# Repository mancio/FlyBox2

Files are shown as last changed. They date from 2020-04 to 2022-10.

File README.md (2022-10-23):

# FlyBox2

<p align="center">
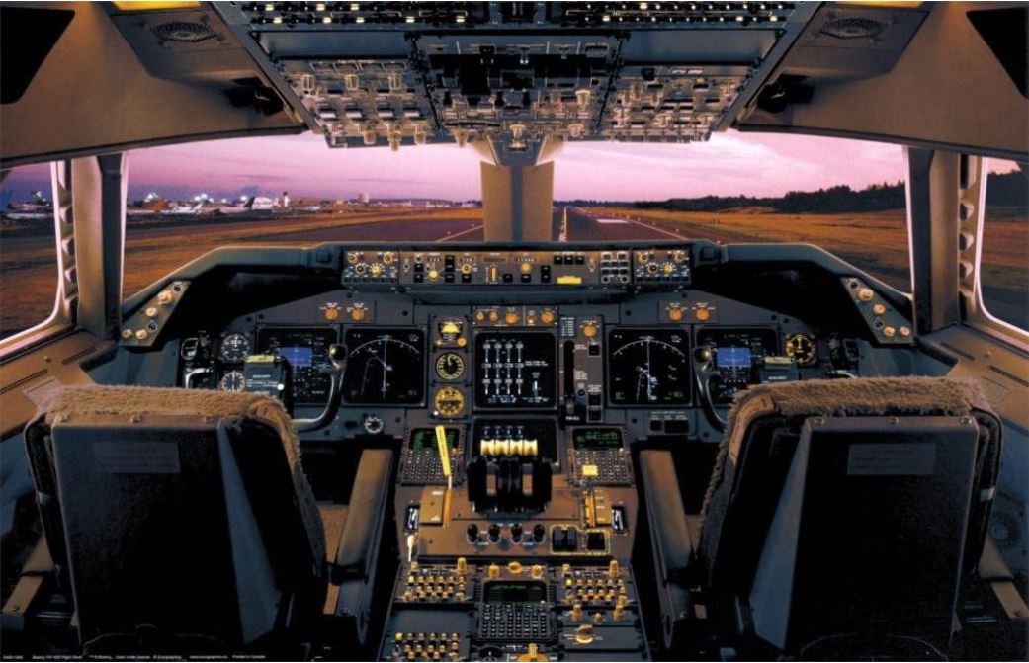
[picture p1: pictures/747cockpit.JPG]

</p>

An advanced flight control pad made with an atmega32u4 pro micro (leonardo architecture)

This idea is the evolution of the first [FlyBox](https://github.com/mancio/FlyBox) a pad to be used with a joystick to control all the operation with the hand free from the axis flight controls. FlyBox2 bring the basic idea to a new level.
To keep low prices is possible to use two Arduino and a multiplexer to have multiple interrupt pins for encoders and many push button.
The main Arduino will collect signal from the other and will send to the PC using the HID driver. 

## The Arduino Pro Micro
[Full Pinout](https://cdn.sparkfun.com/datasheets/Dev/Arduino/Boards/ProMicro16MHzv1.pdf)

For better performance remember to use interrupt pins for encoder. 

Interrupt pins are 0,1,2,3,7.

## IDE
VS Studio Visual Studio Code 

## Schematics

<p align="center">
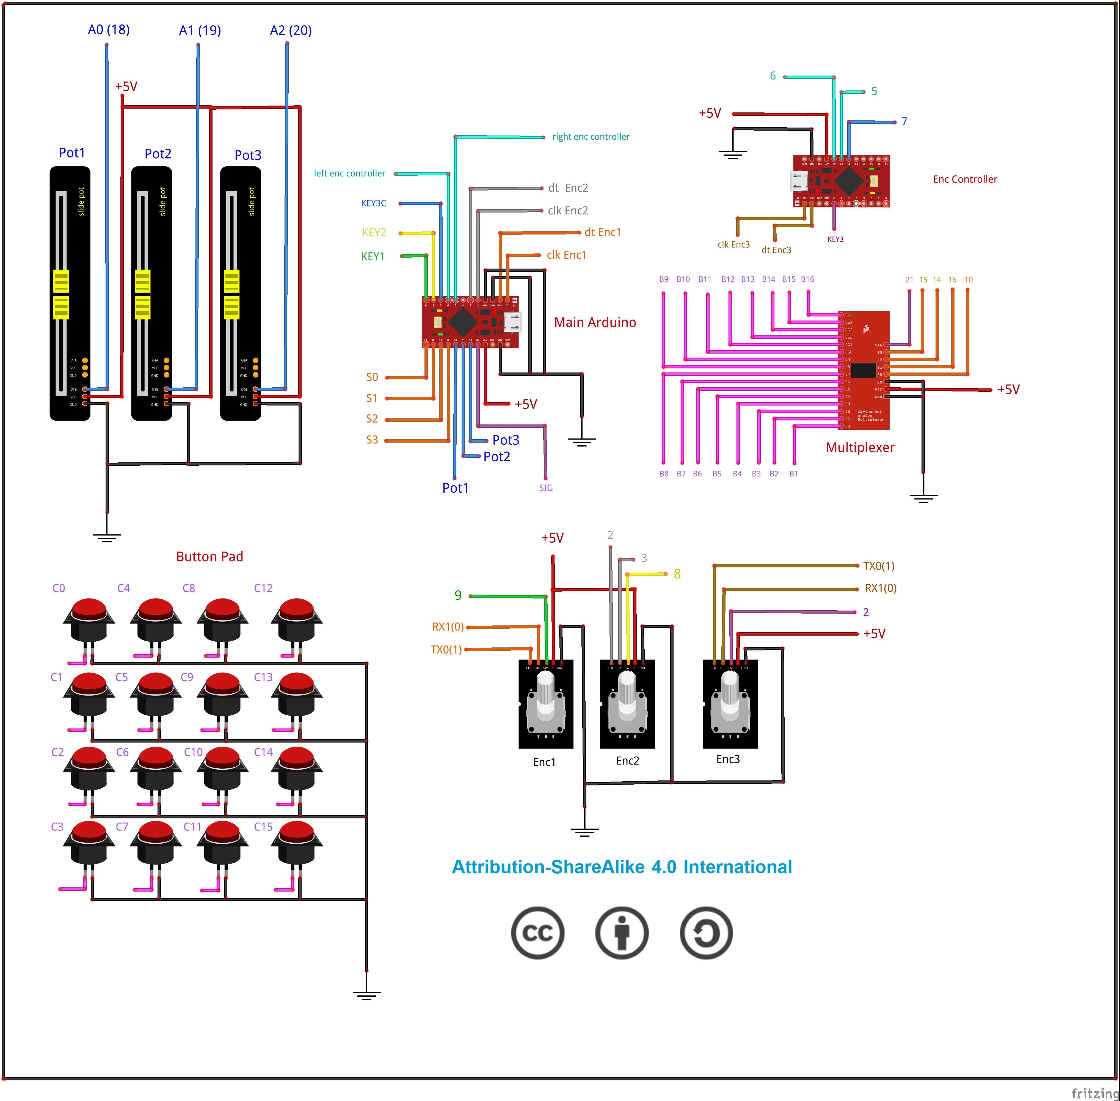
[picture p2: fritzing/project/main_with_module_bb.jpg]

</p>

## MC14490P Signal Debounce Module

I build a small module to fit the [MC14490P](https://www.onsemi.com/pub/Collateral/MC14490-D.PDF) a debouncer signal chip. The delay can be changed by changing the cap impedance. Bigger value = bigger delay.
The hardware approach help the software debounce, anyway is just an optional.

You can find the board ready to print on [OSHPark](https://oshpark.com/shared_projects/8fIAeRlI)

## The encoder tragedy 

Unfortunately the Pro Micro has only 5 interrupt (pins: 0,1,2,3,7). If we wire the encoder output pins to not-external interrupt pins of Arduino, the encoder will become very imprecise showing movement in the both directions during one side turn of the knob.
This happen because classic pins can be read every loop, instead an external interrupt is catch immediately, so we can say like is "over the loop".
Every encoder need 2 interrupts so we do not have enough pins available for 3 or more knobs.

To solve this issue I decide to build an additional module to attach to this board: [The FlyBox2_encoder_module](https://github.com/mancio/FlyBox2_encoder_module)

## The CD74HC4067 Multiplexer

The multiplexer give the possibility, as the name say, to have many output from few inputs. This can be done by using a
reading input pin and a function that connect all the multiplexed pin to this input one by one. The switch is done by using a [truth table](https://www.instructables.com/id/Tutorial-74HC4067-16-Channel-Analog-Multiplexer-De/).

One easier solution should be using a button matrix having less pins but in this case I cannot press multiple button at the same 
time.

## Component list

* 1x Arduino pro micro atmega32u4 (native USB port not like Arduino nano)
* 3x 10k slide potentiometers
* 3x rotary encoders 
* 1x CD74HC4067 16-Channel Analog Digital Multiplexers
* 1x MC14490P hardware debouncer
* 1x 10nf capacitor(change capacitor change delay)
* 16X push buttons

## Documentation

[Here](http://mancioboxblog.altervista.org/flybox2Doc/files.html) you can find the documentations written in Doxygen 

## Installation

* upload the code of Flybox2 to the main arduino
* unplug the usb from this arduino and plug to the second one
* upload the code of the [Flybox2_encoder_module](https://github.com/mancio/FlyBox2_encoder_module) to the second arduino
* unplug usb and plug again to the first one to play

NOTE: DO NOT PLUG TWO USB AT THE SAME TIME. 5V+ AND GND ARE IN COMMON ON BOTH ARDUINO
ALTHOUGH NOTHING BAD SHOULD HAPPEN IS NOT RECOMMENDED TO HAVE TWO POWER SOURCES.

## Clion UPDATE

For people who like Intellj CLion IDE

* install PlatformIO plug in
* search ``Cmake`` in ``Settings`` and click ``+`` button to add ``Debug``, ``leonardo`` and ``Default``
* install python3
* autogenerate ``CmakeList.txt`` if not present
* add PlatformIO configuration on the top dropdown list (build/play section)
* remove build execution from the configuration list of this new configuration
* play the configuration with leonardo selected ``PlatformIO Upload|leonardo``

some links:
* [tutorial](https://docs.platformio.org/en/latest/integration/ide/clion.html)
* [python trick](https://community.platformio.org/t/could-not-find-the-package-with-requirements-for-your-system-windows-amd64/18416)

## Sliding potentiometer UPDATE

Some sim like DCS are more sensible to potentiometer flickering. As you may notice classic hobbyist use 
pot slide and not, due to their cheap building are not keeping constant resistance in some position.
You will see the throttle of your plane vibrate and changing speed.
This problem can be solved by adding a capacitor (same concept as button debouncing) or via software.
Speaking about the software way, I found a [solution online](https://www.norwegiancreations.com/2015/10/tutorial-potentiometers-with-arduino-and-filtering/) that
involve a moving average algorithm. Even though look like very professional, I thought something much 
more simple. my code has a

* pot map function (from Arduino library)
* joystick function top set the axis scale (from Joystick.h)

With the first I can map the slider following the arduino library suggestions and with the second I can choose
how many axis positions the joystick can take (read by the operating system).
If I map a bigger range of int numbers in one smaller I will have multiple numbers in input assigned to the same
number in output. This magically will remove the vibration!.... so much math saved :)

## Altium Design

In Altium design folder you can find the design for
* [FlyBox2 Main Board](https://github.com/mancio/FlyBox2/tree/master/AltiumProject/Flybox2_main_board)
* [16 Push Button Pad](https://github.com/mancio/FlyBox2/tree/master/AltiumProject/ButtonPad)
* [Breakout module for encoders](https://github.com/mancio/FlyBox2/tree/master/AltiumProject/Encoder_Breakout_Module)
* [Breakout module for potentiometer](https://github.com/mancio/FlyBox2/tree/master/AltiumProject/Potentiometer_breakout_module)
* [Debounce signal module](https://github.com/mancio/FlyBox2/tree/master/AltiumProject/MC14490P_module)

Gerbers file are generated by .OutJob file. This file need to be configured in different why depending by the
format accepted by the printer service.
Altium using the job file is able to generate the gerber file in the specified folder. You need just to zip the output in a single file and upload it on your favorite printing web site service.

I tried
* [OSH Park](https://oshpark.com/)
* [Aisler](https://aisler.net/)
* [JLCPCB](https://jlcpcb.com/)

OSH Park unfortunately seem to be the most problematic accepting files. Is possible you need to customize the .zip file.
The others are fine.

Always write directly to the customer service to check if the design is fine before ordering. Every service interpret gerber
files in different ways.

## Box Design

I tried to design the box using cardboard and unfortunately the result wasn't so good. 
I made the template using Adobe Illustrator because is able to manage svg files. [Here](https://github.com/mancio/FlyBox2/tree/master/artdesign) you can find the project.

Looking for a better solution, I made a box using Fusion 360 [here](https://github.com/mancio/FlyBox2/tree/master/artdesign/fusion360). 

Now is the time for printing and if you live in Poland you can look at [this site](https://send3d.eu/). I still have to try them but price are amazing!

## TODO

* video on youtube (to show how much I'm cool 😎)

## What next?

* improve encoder functionality (when it turn fast is recognize as single click)
* refurbish the design using a Teensy (it has multiple interrupt pins and bigger frequency)
* try using a fpga board (push buttons operation and encoding can be hardwired to save CPU)

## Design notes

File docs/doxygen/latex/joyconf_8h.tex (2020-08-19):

\hypertarget{joyconf_8h}{}\doxysection{C\+:/\+Users/mancio/\+Documents/\+V\+S\+Code/\+Fly\+Box2/include/joyconf.h File Reference}
\label{joyconf_8h}\index{C:/Users/mancio/Documents/VSCode/FlyBox2/include/joyconf.h@{C:/Users/mancio/Documents/VSCode/FlyBox2/include/joyconf.h}}
\doxysubsection*{Macros}
\begin{DoxyCompactItemize}
\item 
\#define \mbox{\hyperlink{joyconf_8h_af62b1614b9bf8609ff4f99706498dade}{N\+O\+\_\+\+R\+EV}}~true
\item 
\#define \mbox{\hyperlink{joyconf_8h_a33a42d6bfefe54ae2384f5c28dd87340}{R\+EV}}~false
\end{DoxyCompactItemize}
\doxysubsection*{Functions}
\begin{DoxyCompactItemize}
\item 
void \mbox{\hyperlink{joyconf_8h_afab08082007163b964f41ba8334b865a}{set\+Test}} (bool testin)
\item 
void \mbox{\hyperlink{joyconf_8h_aba818122d70d2c4ac723a578e75f7a3e}{joy\+\_\+conf}} ()
\item 
int \mbox{\hyperlink{joyconf_8h_af953debc945efa2555f04021970412cc}{debouncer}} (int button)
\item 
void \mbox{\hyperlink{joyconf_8h_a8cb8e263f5b6ea299e26646c0c08ce44}{btset}} (int pin, int button)
\item 
long \mbox{\hyperlink{joyconf_8h_a49cc520c407e8c57083155e620ed15d6}{mapper}} (long m, bool rev)
\item 
long \mbox{\hyperlink{joyconf_8h_aca616a67e14e1af19f4c36eedb9ae19d}{setX}} (int pin, bool rev)
\item 
long \mbox{\hyperlink{joyconf_8h_a68d0ce74156f4fb9ca09c7e738bcbf5b}{setY}} (int pin, bool rev)
\item 
long \mbox{\hyperlink{joyconf_8h_a4251eb0b20a921657f56758a51659964}{setZ}} (int pin, bool rev)
\item 
void \mbox{\hyperlink{joyconf_8h_ae830efa40aedd3af609d7ff5d406a782}{bt\+Array\+Filler}} ()
\item 
void \mbox{\hyperlink{joyconf_8h_a7fd8c17ec4e20e74986b3c51041f4026}{mux\+Looper}} ()
\item 
void \mbox{\hyperlink{joyconf_8h_a2b3557d5e92d039ce5744f99efe4efa2}{set\+Encoders\+\_\+dir}} ()
\end{DoxyCompactItemize}

\doxysubsection{Macro Definition Documentation}
\mbox{\Hypertarget{joyconf_8h_af62b1614b9bf8609ff4f99706498dade}\label{joyconf_8h_af62b1614b9bf8609ff4f99706498dade}} 
\index{joyconf.h@{joyconf.h}!NO\_REV@{NO\_REV}}
\index{NO\_REV@{NO\_REV}!joyconf.h@{joyconf.h}}
\doxysubsubsection{\texorpdfstring{NO\_REV}{NO\_REV}}
{\footnotesize\ttfamily \#define N\+O\+\_\+\+R\+EV~true}

Definition at line 26 of file joyconf.\+h.

\mbox{\Hypertarget{joyconf_8h_a33a42d6bfefe54ae2384f5c28dd87340}\label{joyconf_8h_a33a42d6bfefe54ae2384f5c28dd87340}} 
\index{joyconf.h@{joyconf.h}!REV@{REV}}
\index{REV@{REV}!joyconf.h@{joyconf.h}}
\doxysubsubsection{\texorpdfstring{REV}{REV}}
{\footnotesize\ttfamily \#define R\+EV~false}

Definition at line 27 of file joyconf.\+h.

\doxysubsection{Function Documentation}
\mbox{\Hypertarget{joyconf_8h_ae830efa40aedd3af609d7ff5d406a782}\label{joyconf_8h_ae830efa40aedd3af609d7ff5d406a782}} 
\index{joyconf.h@{joyconf.h}!btArrayFiller@{btArrayFiller}}
\index{btArrayFiller@{btArrayFiller}!joyconf.h@{joyconf.h}}
\doxysubsubsection{\texorpdfstring{btArrayFiller()}{btArrayFiller()}}
{\footnotesize\ttfamily void bt\+Array\+Filler (\begin{DoxyParamCaption}{ }\end{DoxyParamCaption})}

build an array of buttons in normal order from 1 to 16 

Definition at line 217 of file joyconf.\+cpp.

\mbox{\Hypertarget{joyconf_8h_a8cb8e263f5b6ea299e26646c0c08ce44}\label{joyconf_8h_a8cb8e263f5b6ea299e26646c0c08ce44}} 
\index{joyconf.h@{joyconf.h}!btset@{btset}}
\index{btset@{btset}!joyconf.h@{joyconf.h}}
\doxysubsubsection{\texorpdfstring{btset()}{btset()}}
{\footnotesize\ttfamily void btset (\begin{DoxyParamCaption}\item[{int}]{pin,  }\item[{int}]{button }\end{DoxyParamCaption})}

set joystick button state according to pin input

\begin{DoxyParams}{Parameters}
{\em int} & input pin \\
\hline
{\em int} & button to be modified \\
\hline
\end{DoxyParams}
\mbox{\Hypertarget{joyconf_8h_af953debc945efa2555f04021970412cc}\label{joyconf_8h_af953debc945efa2555f04021970412cc}} 
\index{joyconf.h@{joyconf.h}!debouncer@{debouncer}}
\index{debouncer@{debouncer}!joyconf.h@{joyconf.h}}
\doxysubsubsection{\texorpdfstring{debouncer()}{debouncer()}}
{\footnotesize\ttfamily int debouncer (\begin{DoxyParamCaption}\item[{int}]{button }\end{DoxyParamCaption})}

debounce the click button (used in addiction with hardware debounce)

\begin{DoxyParams}{Parameters}
{\em int} & button to debounce \\
\hline
\end{DoxyParams}
\begin{DoxyReturn}{Returns}
button state debounced 
\end{DoxyReturn}

Definition at line 138 of file joyconf.\+cpp.

\mbox{\Hypertarget{joyconf_8h_aba818122d70d2c4ac723a578e75f7a3e}\label{joyconf_8h_aba818122d70d2c4ac723a578e75f7a3e}} 
\index{joyconf.h@{joyconf.h}!joy\_conf@{joy\_conf}}
\index{joy\_conf@{joy\_conf}!joyconf.h@{joyconf.h}}
\doxysubsubsection{\texorpdfstring{joy\_conf()}{joy\_conf()}}
{\footnotesize\ttfamily void joy\+\_\+conf (\begin{DoxyParamCaption}{ }\end{DoxyParamCaption})}

Initialize joystick library 

Definition at line 122 of file joyconf.\+cpp.

\mbox{\Hypertarget{joyconf_8h_a49cc520c407e8c57083155e620ed15d6}\label{joyconf_8h_a49cc520c407e8c57083155e620ed15d6}} 
\index{joyconf.h@{joyconf.h}!mapper@{mapper}}
\index{mapper@{mapper}!joyconf.h@{joyconf.h}}
\doxysubsubsection{\texorpdfstring{mapper()}{mapper()}}
{\footnotesize\ttfamily long mapper (\begin{DoxyParamCaption}\item[{long}]{m,  }\item[{bool}]{rev }\end{DoxyParamCaption})}

map the potentiometer scale to the Arduino analog input scale

\begin{DoxyParams}{Parameters}
{\em long} & input analog value from axis \\
\hline
{\em bool} & invert axis if false\\
\hline
\end{DoxyParams}
\begin{DoxyReturn}{Returns}
mapped value as long 
\end{DoxyReturn}

Definition at line 179 of file joyconf.\+cpp.

\mbox{\Hypertarget{joyconf_8h_a7fd8c17ec4e20e74986b3c51041f4026}\label{joyconf_8h_a7fd8c17ec4e20e74986b3c51041f4026}} 
\index{joyconf.h@{joyconf.h}!muxLooper@{muxLooper}}
\index{muxLooper@{muxLooper}!joyconf.h@{joyconf.h}}
\doxysubsubsection{\texorpdfstring{muxLooper()}{muxLooper()}}
{\footnotesize\ttfamily void mux\+Looper (\begin{DoxyParamCaption}{ }\end{DoxyParamCaption})}

loop the the multiplexer 16 pin connecting each of them to the S\+IG pin and write the input on the right joystick button. 

Definition at line 226 of file joyconf.\+cpp.

\mbox{\Hypertarget{joyconf_8h_a2b3557d5e92d039ce5744f99efe4efa2}\label{joyconf_8h_a2b3557d5e92d039ce5744f99efe4efa2}} 
\index{joyconf.h@{joyconf.h}!setEncoders\_dir@{setEncoders\_dir}}
\index{setEncoders\_dir@{setEncoders\_dir}!joyconf.h@{joyconf.h}}
\doxysubsubsection{\texorpdfstring{setEncoders\_dir()}{setEncoders\_dir()}}
{\footnotesize\ttfamily void set\+Encoders\+\_\+dir (\begin{DoxyParamCaption}{ }\end{DoxyParamCaption})}

push buttons depending by encoders direction and click buttons 

Definition at line 242 of file joyconf.\+cpp.

\mbox{\Hypertarget{joyconf_8h_afab08082007163b964f41ba8334b865a}\label{joyconf_8h_afab08082007163b964f41ba8334b865a}} 
\index{joyconf.h@{joyconf.h}!setTest@{setTest}}
\index{setTest@{setTest}!joyconf.h@{joyconf.h}}
\doxysubsubsection{\texorpdfstring{setTest()}{setTest()}}
{\footnotesize\ttfamily void set\+Test (\begin{DoxyParamCaption}\item[{bool}]{testin }\end{DoxyParamCaption})}

set the execution in test mode

\begin{DoxyParams}{Parameters}
{\em bool} & if true test mode, if false normal mode \\
\hline
\end{DoxyParams}

Definition at line 118 of file joyconf.\+cpp.

\mbox{\Hypertarget{joyconf_8h_aca616a67e14e1af19f4c36eedb9ae19d}\label{joyconf_8h_aca616a67e14e1af19f4c36eedb9ae19d}} 
\index{joyconf.h@{joyconf.h}!setX@{setX}}
\index{setX@{setX}!joyconf.h@{joyconf.h}}
\doxysubsubsection{\texorpdfstring{setX()}{setX()}}
{\footnotesize\ttfamily long setX (\begin{DoxyParamCaption}\item[{int}]{pin,  }\item[{bool}]{rev }\end{DoxyParamCaption})}

check and set X-\/axis input value

\begin{DoxyParams}{Parameters}
{\em int} & pin number \\
\hline
{\em bool} & if false reverse the axis\\
\hline
\end{DoxyParams}
\begin{DoxyReturn}{Returns}
long axis value 
\end{DoxyReturn}

Definition at line 187 of file joyconf.\+cpp.

\mbox{\Hypertarget{joyconf_8h_a68d0ce74156f4fb9ca09c7e738bcbf5b}\label{joyconf_8h_a68d0ce74156f4fb9ca09c7e738bcbf5b}} 
\index{joyconf.h@{joyconf.h}!setY@{setY}}
\index{setY@{setY}!joyconf.h@{joyconf.h}}
\doxysubsubsection{\texorpdfstring{setY()}{setY()}}
{\footnotesize\ttfamily long setY (\begin{DoxyParamCaption}\item[{int}]{pin,  }\item[{bool}]{rev }\end{DoxyParamCaption})}

check and set Y-\/axis input value

\begin{DoxyParams}{Parameters}
{\em int} & pin number \\
\hline
{\em bool} & if false reverse the axis\\
\hline
\end{DoxyParams}
\begin{DoxyReturn}{Returns}
long axis value 
\end{DoxyReturn}

Definition at line 197 of file joyconf.\+cpp.

\mbox{\Hypertarget{joyconf_8h_a4251eb0b20a921657f56758a51659964}\label{joyconf_8h_a4251eb0b20a921657f56758a51659964}} 
\index{joyconf.h@{joyconf.h}!setZ@{setZ}}
\index{setZ@{setZ}!joyconf.h@{joyconf.h}}
\doxysubsubsection{\texorpdfstring{setZ()}{setZ()}}
{\footnotesize\ttfamily long setZ (\begin{DoxyParamCaption}\item[{int}]{pin,  }\item[{bool}]{rev }\end{DoxyParamCaption})}

check and set Z-\/axis input value

\begin{DoxyParams}{Parameters}
{\em int} & pin number \\
\hline
{\em bool} & if false reverse the axis\\
\hline
\end{DoxyParams}
\begin{DoxyReturn}{Returns}
long axis value 
\end{DoxyReturn}

Definition at line 207 of file joyconf.\+cpp.

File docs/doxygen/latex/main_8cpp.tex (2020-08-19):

\hypertarget{main_8cpp}{}\doxysection{C\+:/\+Users/mancio/\+Documents/\+V\+S\+Code/\+Fly\+Box2/src/main.cpp File Reference}
\label{main_8cpp}\index{C:/Users/mancio/Documents/VSCode/FlyBox2/src/main.cpp@{C:/Users/mancio/Documents/VSCode/FlyBox2/src/main.cpp}}
{\ttfamily \#include $<$Arduino.\+h$>$}\newline
{\ttfamily \#include $<$ports.\+h$>$}\newline
{\ttfamily \#include $<$setports.\+h$>$}\newline
{\ttfamily \#include $<$setmicro.\+h$>$}\newline
{\ttfamily \#include $<$joyconf.\+h$>$}\newline
{\ttfamily \#include $<$emulator.\+h$>$}\newline
{\ttfamily \#include $<$logger.\+h$>$}\newline
{\ttfamily \#include $<$Timer.\+h$>$}\newline
\doxysubsection*{Functions}
\begin{DoxyCompactItemize}
\item 
void \mbox{\hyperlink{main_8cpp_a4fc01d736fe50cf5b977f755b675f11d}{setup}} ()
\item 
void \mbox{\hyperlink{main_8cpp_afe461d27b9c48d5921c00d521181f12f}{loop}} ()
\end{DoxyCompactItemize}
\doxysubsection*{Variables}
\begin{DoxyCompactItemize}
\item 
bool \mbox{\hyperlink{main_8cpp_aad8aa83f1f5c3ca85ddf0032489d6ba0}{t}} = false
\item 
bool \mbox{\hyperlink{main_8cpp_a746d2c83ca0ca12266fcb15852226dcd}{l}} = false
\item 
\mbox{\hyperlink{class_timer__}{Timer\+\_\+}} \mbox{\hyperlink{main_8cpp_a4091b25cca5413fc53d7583b2960072c}{Timer\+\_\+main}}
\item 
\mbox{\hyperlink{class_timer__}{Timer\+\_\+}} \mbox{\hyperlink{main_8cpp_a7243ef0ac820ca89a7aaec118f8bfe31}{Enc\+\_\+speed}}
\end{DoxyCompactItemize}

\doxysubsection{Function Documentation}
\mbox{\Hypertarget{main_8cpp_afe461d27b9c48d5921c00d521181f12f}\label{main_8cpp_afe461d27b9c48d5921c00d521181f12f}} 
\index{main.cpp@{main.cpp}!loop@{loop}}
\index{loop@{loop}!main.cpp@{main.cpp}}
\doxysubsubsection{\texorpdfstring{loop()}{loop()}}
{\footnotesize\ttfamily void loop (\begin{DoxyParamCaption}{ }\end{DoxyParamCaption})}

Definition at line 54 of file main.\+cpp.

\mbox{\Hypertarget{main_8cpp_a4fc01d736fe50cf5b977f755b675f11d}\label{main_8cpp_a4fc01d736fe50cf5b977f755b675f11d}} 
\index{main.cpp@{main.cpp}!setup@{setup}}
\index{setup@{setup}!main.cpp@{main.cpp}}
\doxysubsubsection{\texorpdfstring{setup()}{setup()}}
{\footnotesize\ttfamily void setup (\begin{DoxyParamCaption}{ }\end{DoxyParamCaption})}

Definition at line 44 of file main.\+cpp.

\doxysubsection{Variable Documentation}
\mbox{\Hypertarget{main_8cpp_a7243ef0ac820ca89a7aaec118f8bfe31}\label{main_8cpp_a7243ef0ac820ca89a7aaec118f8bfe31}} 
\index{main.cpp@{main.cpp}!Enc\_speed@{Enc\_speed}}
\index{Enc\_speed@{Enc\_speed}!main.cpp@{main.cpp}}
\doxysubsubsection{\texorpdfstring{Enc\_speed}{Enc\_speed}}
{\footnotesize\ttfamily \mbox{\hyperlink{class_timer__}{Timer\+\_\+}} Enc\+\_\+speed}

Definition at line 42 of file main.\+cpp.

\mbox{\Hypertarget{main_8cpp_a746d2c83ca0ca12266fcb15852226dcd}\label{main_8cpp_a746d2c83ca0ca12266fcb15852226dcd}} 
\index{main.cpp@{main.cpp}!l@{l}}
\index{l@{l}!main.cpp@{main.cpp}}
\doxysubsubsection{\texorpdfstring{l}{l}}
{\footnotesize\ttfamily bool l = false}

Definition at line 39 of file main.\+cpp.

\mbox{\Hypertarget{main_8cpp_aad8aa83f1f5c3ca85ddf0032489d6ba0}\label{main_8cpp_aad8aa83f1f5c3ca85ddf0032489d6ba0}} 
\index{main.cpp@{main.cpp}!t@{t}}
\index{t@{t}!main.cpp@{main.cpp}}
\doxysubsubsection{\texorpdfstring{t}{t}}
{\footnotesize\ttfamily bool t = false}

Definition at line 33 of file main.\+cpp.

\mbox{\Hypertarget{main_8cpp_a4091b25cca5413fc53d7583b2960072c}\label{main_8cpp_a4091b25cca5413fc53d7583b2960072c}} 
\index{main.cpp@{main.cpp}!Timer\_main@{Timer\_main}}
\index{Timer\_main@{Timer\_main}!main.cpp@{main.cpp}}
\doxysubsubsection{\texorpdfstring{Timer\_main}{Timer\_main}}
{\footnotesize\ttfamily \mbox{\hyperlink{class_timer__}{Timer\+\_\+}} Timer\+\_\+main}

Definition at line 41 of file main.\+cpp.

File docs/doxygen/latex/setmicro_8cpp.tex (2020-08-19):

\hypertarget{setmicro_8cpp}{}\doxysection{C\+:/\+Users/mancio/\+Documents/\+V\+S\+Code/\+Fly\+Box2/src/setmicro.cpp File Reference}
\label{setmicro_8cpp}\index{C:/Users/mancio/Documents/VSCode/FlyBox2/src/setmicro.cpp@{C:/Users/mancio/Documents/VSCode/FlyBox2/src/setmicro.cpp}}
{\ttfamily \#include $<$Arduino.\+h$>$}\newline
{\ttfamily \#include $<$setmicro.\+h$>$}\newline
\doxysubsection*{Functions}
\begin{DoxyCompactItemize}
\item 
void \mbox{\hyperlink{setmicro_8cpp_a665e05d2903b9591eaa987e2365bf92a}{set\+Led}} ()
\end{DoxyCompactItemize}

\doxysubsection{Function Documentation}
\mbox{\Hypertarget{setmicro_8cpp_a665e05d2903b9591eaa987e2365bf92a}\label{setmicro_8cpp_a665e05d2903b9591eaa987e2365bf92a}} 
\index{setmicro.cpp@{setmicro.cpp}!setLed@{setLed}}
\index{setLed@{setLed}!setmicro.cpp@{setmicro.cpp}}
\doxysubsubsection{\texorpdfstring{setLed()}{setLed()}}
{\footnotesize\ttfamily void set\+Led (\begin{DoxyParamCaption}{ }\end{DoxyParamCaption})}

turn on and off Arduino build in leds 

Definition at line 26 of file setmicro.\+cpp.

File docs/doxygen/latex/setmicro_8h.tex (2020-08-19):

\hypertarget{setmicro_8h}{}\doxysection{C\+:/\+Users/mancio/\+Documents/\+V\+S\+Code/\+Fly\+Box2/include/setmicro.h File Reference}
\label{setmicro_8h}\index{C:/Users/mancio/Documents/VSCode/FlyBox2/include/setmicro.h@{C:/Users/mancio/Documents/VSCode/FlyBox2/include/setmicro.h}}
\doxysubsection*{Functions}
\begin{DoxyCompactItemize}
\item 
void \mbox{\hyperlink{setmicro_8h_a665e05d2903b9591eaa987e2365bf92a}{set\+Led}} ()
\end{DoxyCompactItemize}

\doxysubsection{Function Documentation}
\mbox{\Hypertarget{setmicro_8h_a665e05d2903b9591eaa987e2365bf92a}\label{setmicro_8h_a665e05d2903b9591eaa987e2365bf92a}} 
\index{setmicro.h@{setmicro.h}!setLed@{setLed}}
\index{setLed@{setLed}!setmicro.h@{setmicro.h}}
\doxysubsubsection{\texorpdfstring{setLed()}{setLed()}}
{\footnotesize\ttfamily void set\+Led (\begin{DoxyParamCaption}{ }\end{DoxyParamCaption})}

turn on and off Arduino build in leds 

Definition at line 26 of file setmicro.\+cpp.

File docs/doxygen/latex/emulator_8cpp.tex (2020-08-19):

\hypertarget{emulator_8cpp}{}\doxysection{C\+:/\+Users/mancio/\+Documents/\+V\+S\+Code/\+Fly\+Box2/src/emulator.cpp File Reference}
\label{emulator_8cpp}\index{C:/Users/mancio/Documents/VSCode/FlyBox2/src/emulator.cpp@{C:/Users/mancio/Documents/VSCode/FlyBox2/src/emulator.cpp}}
{\ttfamily \#include $<$Arduino.\+h$>$}\newline
{\ttfamily \#include $<$Timer.\+h$>$}\newline
{\ttfamily \#include $<$emulator.\+h$>$}\newline
\doxysubsection*{Functions}
\begin{DoxyCompactItemize}
\item 
void \mbox{\hyperlink{emulator_8cpp_acb900d5f801949b0091609d85d37e25e}{reset\+\_\+joy\+\_\+em}} ()
\item 
void \mbox{\hyperlink{emulator_8cpp_a3c792e34150d7d58855cc4d245a5bfa1}{reset\+\_\+bt\+\_\+em}} ()
\item 
void \mbox{\hyperlink{emulator_8cpp_a2a9b9dc760ecfaf5c77a246b4083fad2}{click\+\_\+bt\+\_\+em}} (int button)
\item 
void \mbox{\hyperlink{emulator_8cpp_ab3b03e55b5cef709a1efb1f955827fb3}{move\+\_\+joy\+\_\+em}} (int X, int Y, int Z)
\item 
void \mbox{\hyperlink{emulator_8cpp_afea28a8b36027dda9b0ddca011a72970}{loop\+\_\+joy\+\_\+em}} ()
\item 
void \mbox{\hyperlink{emulator_8cpp_af5dd5ca52895451b2177f681c20e0773}{click\+\_\+enc\+\_\+em}} ()
\item 
int \mbox{\hyperlink{emulator_8cpp_a1a528ab1ed5a111cfd9a4b23158515c8}{read\+\_\+enc}} (int enc)
\item 
void \mbox{\hyperlink{emulator_8cpp_af8ec3988c3eaf3ce7e5cb1cb43457b1f}{reset\+\_\+enc\+\_\+click\+\_\+em}} ()
\item 
void \mbox{\hyperlink{emulator_8cpp_aacf2fb8fefb7f14690e10925c5e79ddc}{click\+\_\+enc\+\_\+em}} (int bt\+\_\+en)
\item 
void \mbox{\hyperlink{emulator_8cpp_a38c47c0ebfb0a617625f431de7fb2de5}{stop\+\_\+enc}} ()
\item 
void \mbox{\hyperlink{emulator_8cpp_a218aea3b253fc0d7a592f6a8196c7509}{mux\+\_\+channel\+\_\+em}} (int ar\+\_\+pos)
\item 
int \mbox{\hyperlink{emulator_8cpp_a13d0023e0965770b4221b0ac490c3c89}{digital\+Read\+\_\+em}} ()
\item 
int \mbox{\hyperlink{emulator_8cpp_aef7ce66ec5d0ab61b0ea673a95c3523a}{analog\+Read\+\_\+em\+\_\+X}} ()
\item 
int \mbox{\hyperlink{emulator_8cpp_a5089d44a1d58b555b48dada10767e5b9}{analog\+Read\+\_\+em\+\_\+Y}} ()
\item 
int \mbox{\hyperlink{emulator_8cpp_a32442d77e3cc41bf9c257a7c3e12d4a8}{analog\+Read\+\_\+em\+\_\+Z}} ()
\end{DoxyCompactItemize}
\doxysubsection*{Variables}
\begin{DoxyCompactItemize}
\item 
int \mbox{\hyperlink{emulator_8cpp_aee8b9f37d92e7be53d534b6be8ea7850}{st\+\_\+array}} \mbox{[}3\mbox{]}
\item 
int \mbox{\hyperlink{emulator_8cpp_a569d506de4974c4afb12268f3cb74779}{enc\+\_\+array}} \mbox{[}6\mbox{]}
\item 
int \mbox{\hyperlink{emulator_8cpp_ab4ae7205573977222eadd0795db193e2}{steps}} = 0
\item 
bool \mbox{\hyperlink{emulator_8cpp_a129546315e7dc7fb5b85a971fd0ec42c}{inv}} = true
\item 
int \mbox{\hyperlink{emulator_8cpp_a8aad05f079052b1ec0e556ea8eb7e153}{st\+\_\+bt\+\_\+array}} \mbox{[}16\mbox{]}
\item 
int \mbox{\hyperlink{emulator_8cpp_a998a4d68f1c04ee0d184be64dce5f7fb}{bt\+\_\+em}} = 0
\item 
int \mbox{\hyperlink{emulator_8cpp_a6226ec1ace7f76fb45a2b9bda7acbfb6}{sum\+\_\+X}} = 1
\item 
int \mbox{\hyperlink{emulator_8cpp_a9e7b5afdfacae537ca668907e215f855}{sum\+\_\+Y}} = 1
\item 
int \mbox{\hyperlink{emulator_8cpp_ac957dee83e46a870203d63745f2c75a0}{sum\+\_\+Z}} = 1
\end{DoxyCompactItemize}

\doxysubsection{Function Documentation}
\mbox{\Hypertarget{emulator_8cpp_aef7ce66ec5d0ab61b0ea673a95c3523a}\label{emulator_8cpp_aef7ce66ec5d0ab61b0ea673a95c3523a}} 
\index{emulator.cpp@{emulator.cpp}!analogRead\_em\_X@{analogRead\_em\_X}}
\index{analogRead\_em\_X@{analogRead\_em\_X}!emulator.cpp@{emulator.cpp}}
\doxysubsubsection{\texorpdfstring{analogRead\_em\_X()}{analogRead\_em\_X()}}
{\footnotesize\ttfamily int analog\+Read\+\_\+em\+\_\+X (\begin{DoxyParamCaption}{ }\end{DoxyParamCaption})}

return the value from emulated X

\begin{DoxyReturn}{Returns}
emulated X value (0-\/1023) 
\end{DoxyReturn}

Definition at line 168 of file emulator.\+cpp.

\mbox{\Hypertarget{emulator_8cpp_a5089d44a1d58b555b48dada10767e5b9}\label{emulator_8cpp_a5089d44a1d58b555b48dada10767e5b9}} 
\index{emulator.cpp@{emulator.cpp}!analogRead\_em\_Y@{analogRead\_em\_Y}}
\index{analogRead\_em\_Y@{analogRead\_em\_Y}!emulator.cpp@{emulator.cpp}}
\doxysubsubsection{\texorpdfstring{analogRead\_em\_Y()}{analogRead\_em\_Y()}}
{\footnotesize\ttfamily int analog\+Read\+\_\+em\+\_\+Y (\begin{DoxyParamCaption}{ }\end{DoxyParamCaption})}

return the value from emulated Y

\begin{DoxyReturn}{Returns}
emulated Y value (0-\/1023) 
\end{DoxyReturn}

Definition at line 172 of file emulator.\+cpp.

\mbox{\Hypertarget{emulator_8cpp_a32442d77e3cc41bf9c257a7c3e12d4a8}\label{emulator_8cpp_a32442d77e3cc41bf9c257a7c3e12d4a8}} 
\index{emulator.cpp@{emulator.cpp}!analogRead\_em\_Z@{analogRead\_em\_Z}}
\index{analogRead\_em\_Z@{analogRead\_em\_Z}!emulator.cpp@{emulator.cpp}}
\doxysubsubsection{\texorpdfstring{analogRead\_em\_Z()}{analogRead\_em\_Z()}}
{\footnotesize\ttfamily int analog\+Read\+\_\+em\+\_\+Z (\begin{DoxyParamCaption}{ }\end{DoxyParamCaption})}

return the value from emulated Z

\begin{DoxyReturn}{Returns}
emulated Z value (0-\/1023) 
\end{DoxyReturn}

Definition at line 176 of file emulator.\+cpp.

\mbox{\Hypertarget{emulator_8cpp_a2a9b9dc760ecfaf5c77a246b4083fad2}\label{emulator_8cpp_a2a9b9dc760ecfaf5c77a246b4083fad2}} 
\index{emulator.cpp@{emulator.cpp}!click\_bt\_em@{click\_bt\_em}}
\index{click\_bt\_em@{click\_bt\_em}!emulator.cpp@{emulator.cpp}}
\doxysubsubsection{\texorpdfstring{click\_bt\_em()}{click\_bt\_em()}}
{\footnotesize\ttfamily void click\+\_\+bt\+\_\+em (\begin{DoxyParamCaption}\item[{int}]{button }\end{DoxyParamCaption})}

emulate click of button

\begin{DoxyParams}{Parameters}
{\em int} & button to click (from 0 tp 15) \\
\hline
\end{DoxyParams}

Definition at line 98 of file emulator.\+cpp.

\mbox{\Hypertarget{emulator_8cpp_af5dd5ca52895451b2177f681c20e0773}\label{emulator_8cpp_af5dd5ca52895451b2177f681c20e0773}} 
\index{emulator.cpp@{emulator.cpp}!click\_enc\_em@{click\_enc\_em}}
\index{click\_enc\_em@{click\_enc\_em}!emulator.cpp@{emulator.cpp}}
\doxysubsubsection{\texorpdfstring{click\_enc\_em()}{click\_enc\_em()}\hspace{0.1cm}{\footnotesize\ttfamily [1/2]}}
{\footnotesize\ttfamily void click\+\_\+enc\+\_\+em (\begin{DoxyParamCaption}{ }\end{DoxyParamCaption})}

set encoders array right and after 360 steps to left 

Definition at line 125 of file emulator.\+cpp.

\mbox{\Hypertarget{emulator_8cpp_aacf2fb8fefb7f14690e10925c5e79ddc}\label{emulator_8cpp_aacf2fb8fefb7f14690e10925c5e79ddc}} 
\index{emulator.cpp@{emulator.cpp}!click\_enc\_em@{click\_enc\_em}}
\index{click\_enc\_em@{click\_enc\_em}!emulator.cpp@{emulator.cpp}}
\doxysubsubsection{\texorpdfstring{click\_enc\_em()}{click\_enc\_em()}\hspace{0.1cm}{\footnotesize\ttfamily [2/2]}}
{\footnotesize\ttfamily void click\+\_\+enc\+\_\+em (\begin{DoxyParamCaption}\item[{int}]{bt\+\_\+en }\end{DoxyParamCaption})}

emulate a click of a button by changing state in the array

\begin{DoxyParams}{Parameters}
{\em int} & encoder button number (between 3 and 5) \\
\hline
\end{DoxyParams}

Definition at line 150 of file emulator.\+cpp.

\mbox{\Hypertarget{emulator_8cpp_a13d0023e0965770b4221b0ac490c3c89}\label{emulator_8cpp_a13d0023e0965770b4221b0ac490c3c89}} 
\index{emulator.cpp@{emulator.cpp}!digitalRead\_em@{digitalRead\_em}}
\index{digitalRead\_em@{digitalRead\_em}!emulator.cpp@{emulator.cpp}}
\doxysubsubsection{\texorpdfstring{digitalRead\_em()}{digitalRead\_em()}}
{\footnotesize\ttfamily int digital\+Read\+\_\+em (\begin{DoxyParamCaption}{ }\end{DoxyParamCaption})}

read value from array previously set by mux emulator

\begin{DoxyReturn}{Returns}
1 or 0 
\end{DoxyReturn}

Definition at line 164 of file emulator.\+cpp.

\mbox{\Hypertarget{emulator_8cpp_afea28a8b36027dda9b0ddca011a72970}\label{emulator_8cpp_afea28a8b36027dda9b0ddca011a72970}} 
\index{emulator.cpp@{emulator.cpp}!loop\_joy\_em@{loop\_joy\_em}}
\index{loop\_joy\_em@{loop\_joy\_em}!emulator.cpp@{emulator.cpp}}
\doxysubsubsection{\texorpdfstring{loop\_joy\_em()}{loop\_joy\_em()}}
{\footnotesize\ttfamily void loop\+\_\+joy\+\_\+em (\begin{DoxyParamCaption}{ }\end{DoxyParamCaption})}

move emulated axes up and down gradually 

Definition at line 108 of file emulator.\+cpp.

\mbox{\Hypertarget{emulator_8cpp_ab3b03e55b5cef709a1efb1f955827fb3}\label{emulator_8cpp_ab3b03e55b5cef709a1efb1f955827fb3}} 
\index{emulator.cpp@{emulator.cpp}!move\_joy\_em@{move\_joy\_em}}
\index{move\_joy\_em@{move\_joy\_em}!emulator.cpp@{emulator.cpp}}
\doxysubsubsection{\texorpdfstring{move\_joy\_em()}{move\_joy\_em()}}
{\footnotesize\ttfamily void move\+\_\+joy\+\_\+em (\begin{DoxyParamCaption}\item[{int}]{X,  }\item[{int}]{Y,  }\item[{int}]{Z }\end{DoxyParamCaption})}

set joystick axes in the emulator array

\begin{DoxyParams}{Parameters}
{\em int} & X \\
\hline
{\em int} & Y \\
\hline
{\em int} & Z \\
\hline
\end{DoxyParams}

Definition at line 102 of file emulator.\+cpp.

\mbox{\Hypertarget{emulator_8cpp_a218aea3b253fc0d7a592f6a8196c7509}\label{emulator_8cpp_a218aea3b253fc0d7a592f6a8196c7509}} 
\index{emulator.cpp@{emulator.cpp}!mux\_channel\_em@{mux\_channel\_em}}
\index{mux\_channel\_em@{mux\_channel\_em}!emulator.cpp@{emulator.cpp}}
\doxysubsubsection{\texorpdfstring{mux\_channel\_em()}{mux\_channel\_em()}}
{\footnotesize\ttfamily void mux\+\_\+channel\+\_\+em (\begin{DoxyParamCaption}\item[{int}]{ar\+\_\+pos }\end{DoxyParamCaption})}

emulate the multiplexer by reading from an array of button states

\begin{DoxyParams}{Parameters}
{\em int} & array position \\
\hline
\end{DoxyParams}

Definition at line 160 of file emulator.\+cpp.

\mbox{\Hypertarget{emulator_8cpp_a1a528ab1ed5a111cfd9a4b23158515c8}\label{emulator_8cpp_a1a528ab1ed5a111cfd9a4b23158515c8}} 
\index{emulator.cpp@{emulator.cpp}!read\_enc@{read\_enc}}
\index{read\_enc@{read\_enc}!emulator.cpp@{emulator.cpp}}
\doxysubsubsection{\texorpdfstring{read\_enc()}{read\_enc()}}
{\footnotesize\ttfamily int read\+\_\+enc (\begin{DoxyParamCaption}\item[{int}]{enc }\end{DoxyParamCaption})}

read the encoder emulated position from the array 0-\/2 = directions 3-\/5 = click buttons

\begin{DoxyParams}{Parameters}
{\em int} & encoder number\\
\hline
\end{DoxyParams}
\begin{DoxyReturn}{Returns}
encoder position or click state as int 
\end{DoxyReturn}

Definition at line 140 of file emulator.\+cpp.

\mbox{\Hypertarget{emulator_8cpp_a3c792e34150d7d58855cc4d245a5bfa1}\label{emulator_8cpp_a3c792e34150d7d58855cc4d245a5bfa1}} 
\index{emulator.cpp@{emulator.cpp}!reset\_bt\_em@{reset\_bt\_em}}
\index{reset\_bt\_em@{reset\_bt\_em}!emulator.cpp@{emulator.cpp}}
\doxysubsubsection{\texorpdfstring{reset\_bt\_em()}{reset\_bt\_em()}}
{\footnotesize\ttfamily void reset\+\_\+bt\+\_\+em (\begin{DoxyParamCaption}{ }\end{DoxyParamCaption})}

reset state of the emulated buttons to 0; 

Definition at line 92 of file emulator.\+cpp.

\mbox{\Hypertarget{emulator_8cpp_af8ec3988c3eaf3ce7e5cb1cb43457b1f}\label{emulator_8cpp_af8ec3988c3eaf3ce7e5cb1cb43457b1f}} 
\index{emulator.cpp@{emulator.cpp}!reset\_enc\_click\_em@{reset\_enc\_click\_em}}
\index{reset\_enc\_click\_em@{reset\_enc\_click\_em}!emulator.cpp@{emulator.cpp}}
\doxysubsubsection{\texorpdfstring{reset\_enc\_click\_em()}{reset\_enc\_click\_em()}}
{\footnotesize\ttfamily void reset\+\_\+enc\+\_\+click\+\_\+em (\begin{DoxyParamCaption}{ }\end{DoxyParamCaption})}

reset all the encoder buttons to state zero released in the array 

Definition at line 144 of file emulator.\+cpp.

\mbox{\Hypertarget{emulator_8cpp_acb900d5f801949b0091609d85d37e25e}\label{emulator_8cpp_acb900d5f801949b0091609d85d37e25e}} 
\index{emulator.cpp@{emulator.cpp}!reset\_joy\_em@{reset\_joy\_em}}
\index{reset\_joy\_em@{reset\_joy\_em}!emulator.cpp@{emulator.cpp}}
\doxysubsubsection{\texorpdfstring{reset\_joy\_em()}{reset\_joy\_em()}}
{\footnotesize\ttfamily void reset\+\_\+joy\+\_\+em (\begin{DoxyParamCaption}{ }\end{DoxyParamCaption})}

reset the state of the emulated axes to center and buttons to not pressed 

Definition at line 86 of file emulator.\+cpp.

\mbox{\Hypertarget{emulator_8cpp_a38c47c0ebfb0a617625f431de7fb2de5}\label{emulator_8cpp_a38c47c0ebfb0a617625f431de7fb2de5}} 
\index{emulator.cpp@{emulator.cpp}!stop\_enc@{stop\_enc}}
\index{stop\_enc@{stop\_enc}!emulator.cpp@{emulator.cpp}}
\doxysubsubsection{\texorpdfstring{stop\_enc()}{stop\_enc()}}
{\footnotesize\ttfamily void stop\+\_\+enc (\begin{DoxyParamCaption}{ }\end{DoxyParamCaption})}

set encoders to center 

Definition at line 154 of file emulator.\+cpp.

\doxysubsection{Variable Documentation}
\mbox{\Hypertarget{emulator_8cpp_a998a4d68f1c04ee0d184be64dce5f7fb}\label{emulator_8cpp_a998a4d68f1c04ee0d184be64dce5f7fb}} 
\index{emulator.cpp@{emulator.cpp}!bt\_em@{bt\_em}}
\index{bt\_em@{bt\_em}!emulator.cpp@{emulator.cpp}}
\doxysubsubsection{\texorpdfstring{bt\_em}{bt\_em}}
{\footnotesize\ttfamily int bt\+\_\+em = 0}

Definition at line 79 of file emulator.\+cpp.

\mbox{\Hypertarget{emulator_8cpp_a569d506de4974c4afb12268f3cb74779}\label{emulator_8cpp_a569d506de4974c4afb12268f3cb74779}} 
\index{emulator.cpp@{emulator.cpp}!enc\_array@{enc\_array}}
\index{enc\_array@{enc\_array}!emulator.cpp@{emulator.cpp}}
\doxysubsubsection{\texorpdfstring{enc\_array}{enc\_array}}
{\footnotesize\ttfamily int enc\+\_\+array\mbox{[}6\mbox{]}}

{\bfseries Initial value\+:}
\begin{DoxyCode}{0}
\DoxyCodeLine{=\{}
\DoxyCodeLine{    0, }
\DoxyCodeLine{    0, }
\DoxyCodeLine{    0, }
\DoxyCodeLine{    0, }
\DoxyCodeLine{    0, }
\DoxyCodeLine{    0, }
\DoxyCodeLine{\}}

\end{DoxyCode}

Definition at line 44 of file emulator.\+cpp.

\mbox{\Hypertarget{emulator_8cpp_a129546315e7dc7fb5b85a971fd0ec42c}\label{emulator_8cpp_a129546315e7dc7fb5b85a971fd0ec42c}} 
\index{emulator.cpp@{emulator.cpp}!inv@{inv}}
\index{inv@{inv}!emulator.cpp@{emulator.cpp}}
\doxysubsubsection{\texorpdfstring{inv}{inv}}
{\footnotesize\ttfamily bool inv = true}

Definition at line 56 of file emulator.\+cpp.

\mbox{\Hypertarget{emulator_8cpp_aee8b9f37d92e7be53d534b6be8ea7850}\label{emulator_8cpp_aee8b9f37d92e7be53d534b6be8ea7850}} 
\index{emulator.cpp@{emulator.cpp}!st\_array@{st\_array}}
\index{st\_array@{st\_array}!emulator.cpp@{emulator.cpp}}
\doxysubsubsection{\texorpdfstring{st\_array}{st\_array}}
{\footnotesize\ttfamily int st\+\_\+array\mbox{[}3\mbox{]}}

{\bfseries Initial value\+:}
\begin{DoxyCode}{0}
\DoxyCodeLine{= \{}
\DoxyCodeLine{    511, }
\DoxyCodeLine{    511, }
\DoxyCodeLine{    511, }
\DoxyCodeLine{\}}

\end{DoxyCode}

Definition at line 29 of file emulator.\+cpp.

\mbox{\Hypertarget{emulator_8cpp_a8aad05f079052b1ec0e556ea8eb7e153}\label{emulator_8cpp_a8aad05f079052b1ec0e556ea8eb7e153}} 
\index{emulator.cpp@{emulator.cpp}!st\_bt\_array@{st\_bt\_array}}
\index{st\_bt\_array@{st\_bt\_array}!emulator.cpp@{emulator.cpp}}
\doxysubsubsection{\texorpdfstring{st\_bt\_array}{st\_bt\_array}}
{\footnotesize\ttfamily int st\+\_\+bt\+\_\+array\mbox{[}16\mbox{]}}

{\bfseries Initial value\+:}
\begin{DoxyCode}{0}
\DoxyCodeLine{= \{}
\DoxyCodeLine{    0, }
\DoxyCodeLine{    0, }
\DoxyCodeLine{    0, }
\DoxyCodeLine{    0, }
\DoxyCodeLine{    0, }
\DoxyCodeLine{    0, }
\DoxyCodeLine{    0, }
\DoxyCodeLine{    0, }
\DoxyCodeLine{    0, }
\DoxyCodeLine{    0, }
\DoxyCodeLine{    0, }
\DoxyCodeLine{    0, }
\DoxyCodeLine{    0, }
\DoxyCodeLine{    0, }
\DoxyCodeLine{    0, }
\DoxyCodeLine{    0  }
\DoxyCodeLine{\}}

\end{DoxyCode}

Definition at line 59 of file emulator.\+cpp.

\mbox{\Hypertarget{emulator_8cpp_ab4ae7205573977222eadd0795db193e2}\label{emulator_8cpp_ab4ae7205573977222eadd0795db193e2}} 
\index{emulator.cpp@{emulator.cpp}!steps@{steps}}
\index{steps@{steps}!emulator.cpp@{emulator.cpp}}
\doxysubsubsection{\texorpdfstring{steps}{steps}}
{\footnotesize\ttfamily int steps = 0}

Definition at line 54 of file emulator.\+cpp.

\mbox{\Hypertarget{emulator_8cpp_a6226ec1ace7f76fb45a2b9bda7acbfb6}\label{emulator_8cpp_a6226ec1ace7f76fb45a2b9bda7acbfb6}} 
\index{emulator.cpp@{emulator.cpp}!sum\_X@{sum\_X}}
\index{sum\_X@{sum\_X}!emulator.cpp@{emulator.cpp}}
\doxysubsubsection{\texorpdfstring{sum\_X}{sum\_X}}
{\footnotesize\ttfamily int sum\+\_\+X = 1}

Definition at line 82 of file emulator.\+cpp.

\mbox{\Hypertarget{emulator_8cpp_a9e7b5afdfacae537ca668907e215f855}\label{emulator_8cpp_a9e7b5afdfacae537ca668907e215f855}} 
\index{emulator.cpp@{emulator.cpp}!sum\_Y@{sum\_Y}}
\index{sum\_Y@{sum\_Y}!emulator.cpp@{emulator.cpp}}
\doxysubsubsection{\texorpdfstring{sum\_Y}{sum\_Y}}
{\footnotesize\ttfamily int sum\+\_\+Y = 1}

Definition at line 83 of file emulator.\+cpp.

\mbox{\Hypertarget{emulator_8cpp_ac957dee83e46a870203d63745f2c75a0}\label{emulator_8cpp_ac957dee83e46a870203d63745f2c75a0}} 
\index{emulator.cpp@{emulator.cpp}!sum\_Z@{sum\_Z}}
\index{sum\_Z@{sum\_Z}!emulator.cpp@{emulator.cpp}}
\doxysubsubsection{\texorpdfstring{sum\_Z}{sum\_Z}}
{\footnotesize\ttfamily int sum\+\_\+Z = 1}

Definition at line 84 of file emulator.\+cpp.

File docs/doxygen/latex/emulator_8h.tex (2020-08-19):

\hypertarget{emulator_8h}{}\doxysection{C\+:/\+Users/mancio/\+Documents/\+V\+S\+Code/\+Fly\+Box2/include/emulator.h File Reference}
\label{emulator_8h}\index{C:/Users/mancio/Documents/VSCode/FlyBox2/include/emulator.h@{C:/Users/mancio/Documents/VSCode/FlyBox2/include/emulator.h}}
{\ttfamily \#include $<$Arduino.\+h$>$}\newline
\doxysubsection*{Functions}
\begin{DoxyCompactItemize}
\item 
void \mbox{\hyperlink{emulator_8h_acb900d5f801949b0091609d85d37e25e}{reset\+\_\+joy\+\_\+em}} ()
\item 
void \mbox{\hyperlink{emulator_8h_a3c792e34150d7d58855cc4d245a5bfa1}{reset\+\_\+bt\+\_\+em}} ()
\item 
void \mbox{\hyperlink{emulator_8h_a2a9b9dc760ecfaf5c77a246b4083fad2}{click\+\_\+bt\+\_\+em}} (int button)
\item 
void \mbox{\hyperlink{emulator_8h_ab3b03e55b5cef709a1efb1f955827fb3}{move\+\_\+joy\+\_\+em}} (int X, int Y, int Z)
\item 
void \mbox{\hyperlink{emulator_8h_afea28a8b36027dda9b0ddca011a72970}{loop\+\_\+joy\+\_\+em}} ()
\item 
void \mbox{\hyperlink{emulator_8h_af5dd5ca52895451b2177f681c20e0773}{click\+\_\+enc\+\_\+em}} ()
\item 
int \mbox{\hyperlink{emulator_8h_a1a528ab1ed5a111cfd9a4b23158515c8}{read\+\_\+enc}} (int enc)
\item 
void \mbox{\hyperlink{emulator_8h_af8ec3988c3eaf3ce7e5cb1cb43457b1f}{reset\+\_\+enc\+\_\+click\+\_\+em}} ()
\item 
void \mbox{\hyperlink{emulator_8h_aacf2fb8fefb7f14690e10925c5e79ddc}{click\+\_\+enc\+\_\+em}} (int bt\+\_\+en)
\item 
void \mbox{\hyperlink{emulator_8h_a38c47c0ebfb0a617625f431de7fb2de5}{stop\+\_\+enc}} ()
\item 
void \mbox{\hyperlink{emulator_8h_a218aea3b253fc0d7a592f6a8196c7509}{mux\+\_\+channel\+\_\+em}} (int ar\+\_\+pos)
\item 
int \mbox{\hyperlink{emulator_8h_a13d0023e0965770b4221b0ac490c3c89}{digital\+Read\+\_\+em}} ()
\item 
int \mbox{\hyperlink{emulator_8h_aef7ce66ec5d0ab61b0ea673a95c3523a}{analog\+Read\+\_\+em\+\_\+X}} ()
\item 
int \mbox{\hyperlink{emulator_8h_a5089d44a1d58b555b48dada10767e5b9}{analog\+Read\+\_\+em\+\_\+Y}} ()
\item 
int \mbox{\hyperlink{emulator_8h_a32442d77e3cc41bf9c257a7c3e12d4a8}{analog\+Read\+\_\+em\+\_\+Z}} ()
\end{DoxyCompactItemize}

\doxysubsection{Function Documentation}
\mbox{\Hypertarget{emulator_8h_aef7ce66ec5d0ab61b0ea673a95c3523a}\label{emulator_8h_aef7ce66ec5d0ab61b0ea673a95c3523a}} 
\index{emulator.h@{emulator.h}!analogRead\_em\_X@{analogRead\_em\_X}}
\index{analogRead\_em\_X@{analogRead\_em\_X}!emulator.h@{emulator.h}}
\doxysubsubsection{\texorpdfstring{analogRead\_em\_X()}{analogRead\_em\_X()}}
{\footnotesize\ttfamily int analog\+Read\+\_\+em\+\_\+X (\begin{DoxyParamCaption}{ }\end{DoxyParamCaption})}

return the value from emulated X

\begin{DoxyReturn}{Returns}
emulated X value (0-\/1023) 
\end{DoxyReturn}

Definition at line 168 of file emulator.\+cpp.

\mbox{\Hypertarget{emulator_8h_a5089d44a1d58b555b48dada10767e5b9}\label{emulator_8h_a5089d44a1d58b555b48dada10767e5b9}} 
\index{emulator.h@{emulator.h}!analogRead\_em\_Y@{analogRead\_em\_Y}}
\index{analogRead\_em\_Y@{analogRead\_em\_Y}!emulator.h@{emulator.h}}
\doxysubsubsection{\texorpdfstring{analogRead\_em\_Y()}{analogRead\_em\_Y()}}
{\footnotesize\ttfamily int analog\+Read\+\_\+em\+\_\+Y (\begin{DoxyParamCaption}{ }\end{DoxyParamCaption})}

return the value from emulated Y

\begin{DoxyReturn}{Returns}
emulated Y value (0-\/1023) 
\end{DoxyReturn}

Definition at line 172 of file emulator.\+cpp.

\mbox{\Hypertarget{emulator_8h_a32442d77e3cc41bf9c257a7c3e12d4a8}\label{emulator_8h_a32442d77e3cc41bf9c257a7c3e12d4a8}} 
\index{emulator.h@{emulator.h}!analogRead\_em\_Z@{analogRead\_em\_Z}}
\index{analogRead\_em\_Z@{analogRead\_em\_Z}!emulator.h@{emulator.h}}
\doxysubsubsection{\texorpdfstring{analogRead\_em\_Z()}{analogRead\_em\_Z()}}
{\footnotesize\ttfamily int analog\+Read\+\_\+em\+\_\+Z (\begin{DoxyParamCaption}{ }\end{DoxyParamCaption})}

return the value from emulated Z

\begin{DoxyReturn}{Returns}
emulated Z value (0-\/1023) 
\end{DoxyReturn}

Definition at line 176 of file emulator.\+cpp.

\mbox{\Hypertarget{emulator_8h_a2a9b9dc760ecfaf5c77a246b4083fad2}\label{emulator_8h_a2a9b9dc760ecfaf5c77a246b4083fad2}} 
\index{emulator.h@{emulator.h}!click\_bt\_em@{click\_bt\_em}}
\index{click\_bt\_em@{click\_bt\_em}!emulator.h@{emulator.h}}
\doxysubsubsection{\texorpdfstring{click\_bt\_em()}{click\_bt\_em()}}
{\footnotesize\ttfamily void click\+\_\+bt\+\_\+em (\begin{DoxyParamCaption}\item[{int}]{button }\end{DoxyParamCaption})}

emulate click of button

\begin{DoxyParams}{Parameters}
{\em int} & button to click (from 0 tp 15) \\
\hline
\end{DoxyParams}

Definition at line 98 of file emulator.\+cpp.

\mbox{\Hypertarget{emulator_8h_af5dd5ca52895451b2177f681c20e0773}\label{emulator_8h_af5dd5ca52895451b2177f681c20e0773}} 
\index{emulator.h@{emulator.h}!click\_enc\_em@{click\_enc\_em}}
\index{click\_enc\_em@{click\_enc\_em}!emulator.h@{emulator.h}}
\doxysubsubsection{\texorpdfstring{click\_enc\_em()}{click\_enc\_em()}\hspace{0.1cm}{\footnotesize\ttfamily [1/2]}}
{\footnotesize\ttfamily void click\+\_\+enc\+\_\+em (\begin{DoxyParamCaption}{ }\end{DoxyParamCaption})}

set encoders array right and after 360 steps to left 

Definition at line 125 of file emulator.\+cpp.

\mbox{\Hypertarget{emulator_8h_aacf2fb8fefb7f14690e10925c5e79ddc}\label{emulator_8h_aacf2fb8fefb7f14690e10925c5e79ddc}} 
\index{emulator.h@{emulator.h}!click\_enc\_em@{click\_enc\_em}}
\index{click\_enc\_em@{click\_enc\_em}!emulator.h@{emulator.h}}
\doxysubsubsection{\texorpdfstring{click\_enc\_em()}{click\_enc\_em()}\hspace{0.1cm}{\footnotesize\ttfamily [2/2]}}
{\footnotesize\ttfamily void click\+\_\+enc\+\_\+em (\begin{DoxyParamCaption}\item[{int}]{bt\+\_\+en }\end{DoxyParamCaption})}

emulate a click of a button by changing state in the array

\begin{DoxyParams}{Parameters}
{\em int} & encoder button number (between 3 and 5) \\
\hline
\end{DoxyParams}

Definition at line 150 of file emulator.\+cpp.

\mbox{\Hypertarget{emulator_8h_a13d0023e0965770b4221b0ac490c3c89}\label{emulator_8h_a13d0023e0965770b4221b0ac490c3c89}} 
\index{emulator.h@{emulator.h}!digitalRead\_em@{digitalRead\_em}}
\index{digitalRead\_em@{digitalRead\_em}!emulator.h@{emulator.h}}
\doxysubsubsection{\texorpdfstring{digitalRead\_em()}{digitalRead\_em()}}
{\footnotesize\ttfamily int digital\+Read\+\_\+em (\begin{DoxyParamCaption}{ }\end{DoxyParamCaption})}

read value from array previously set by mux emulator

\begin{DoxyReturn}{Returns}
1 or 0 
\end{DoxyReturn}

Definition at line 164 of file emulator.\+cpp.

\mbox{\Hypertarget{emulator_8h_afea28a8b36027dda9b0ddca011a72970}\label{emulator_8h_afea28a8b36027dda9b0ddca011a72970}} 
\index{emulator.h@{emulator.h}!loop\_joy\_em@{loop\_joy\_em}}
\index{loop\_joy\_em@{loop\_joy\_em}!emulator.h@{emulator.h}}
\doxysubsubsection{\texorpdfstring{loop\_joy\_em()}{loop\_joy\_em()}}
{\footnotesize\ttfamily void loop\+\_\+joy\+\_\+em (\begin{DoxyParamCaption}{ }\end{DoxyParamCaption})}

move emulated axes up and down gradually 

Definition at line 108 of file emulator.\+cpp.

\mbox{\Hypertarget{emulator_8h_ab3b03e55b5cef709a1efb1f955827fb3}\label{emulator_8h_ab3b03e55b5cef709a1efb1f955827fb3}} 
\index{emulator.h@{emulator.h}!move\_joy\_em@{move\_joy\_em}}
\index{move\_joy\_em@{move\_joy\_em}!emulator.h@{emulator.h}}
\doxysubsubsection{\texorpdfstring{move\_joy\_em()}{move\_joy\_em()}}
{\footnotesize\ttfamily void move\+\_\+joy\+\_\+em (\begin{DoxyParamCaption}\item[{int}]{X,  }\item[{int}]{Y,  }\item[{int}]{Z }\end{DoxyParamCaption})}

set joystick axes in the emulator array

\begin{DoxyParams}{Parameters}
{\em int} & X \\
\hline
{\em int} & Y \\
\hline
{\em int} & Z \\
\hline
\end{DoxyParams}

Definition at line 102 of file emulator.\+cpp.

\mbox{\Hypertarget{emulator_8h_a218aea3b253fc0d7a592f6a8196c7509}\label{emulator_8h_a218aea3b253fc0d7a592f6a8196c7509}} 
\index{emulator.h@{emulator.h}!mux\_channel\_em@{mux\_channel\_em}}
\index{mux\_channel\_em@{mux\_channel\_em}!emulator.h@{emulator.h}}
\doxysubsubsection{\texorpdfstring{mux\_channel\_em()}{mux\_channel\_em()}}
{\footnotesize\ttfamily void mux\+\_\+channel\+\_\+em (\begin{DoxyParamCaption}\item[{int}]{ar\+\_\+pos }\end{DoxyParamCaption})}

emulate the multiplexer by reading from an array of button states

\begin{DoxyParams}{Parameters}
{\em int} & array position \\
\hline
\end{DoxyParams}

Definition at line 160 of file emulator.\+cpp.

\mbox{\Hypertarget{emulator_8h_a1a528ab1ed5a111cfd9a4b23158515c8}\label{emulator_8h_a1a528ab1ed5a111cfd9a4b23158515c8}} 
\index{emulator.h@{emulator.h}!read\_enc@{read\_enc}}
\index{read\_enc@{read\_enc}!emulator.h@{emulator.h}}
\doxysubsubsection{\texorpdfstring{read\_enc()}{read\_enc()}}
{\footnotesize\ttfamily int read\+\_\+enc (\begin{DoxyParamCaption}\item[{int}]{enc }\end{DoxyParamCaption})}

read the encoder emulated position from the array 0-\/2 = directions 3-\/5 = click buttons

\begin{DoxyParams}{Parameters}
{\em int} & encoder number\\
\hline
\end{DoxyParams}
\begin{DoxyReturn}{Returns}
encoder position or click state as int 
\end{DoxyReturn}

Definition at line 140 of file emulator.\+cpp.

\mbox{\Hypertarget{emulator_8h_a3c792e34150d7d58855cc4d245a5bfa1}\label{emulator_8h_a3c792e34150d7d58855cc4d245a5bfa1}} 
\index{emulator.h@{emulator.h}!reset\_bt\_em@{reset\_bt\_em}}
\index{reset\_bt\_em@{reset\_bt\_em}!emulator.h@{emulator.h}}
\doxysubsubsection{\texorpdfstring{reset\_bt\_em()}{reset\_bt\_em()}}
{\footnotesize\ttfamily void reset\+\_\+bt\+\_\+em (\begin{DoxyParamCaption}{ }\end{DoxyParamCaption})}

reset state of the emulated buttons to 0; 

Definition at line 92 of file emulator.\+cpp.

\mbox{\Hypertarget{emulator_8h_af8ec3988c3eaf3ce7e5cb1cb43457b1f}\label{emulator_8h_af8ec3988c3eaf3ce7e5cb1cb43457b1f}} 
\index{emulator.h@{emulator.h}!reset\_enc\_click\_em@{reset\_enc\_click\_em}}
\index{reset\_enc\_click\_em@{reset\_enc\_click\_em}!emulator.h@{emulator.h}}
\doxysubsubsection{\texorpdfstring{reset\_enc\_click\_em()}{reset\_enc\_click\_em()}}
{\footnotesize\ttfamily void reset\+\_\+enc\+\_\+click\+\_\+em (\begin{DoxyParamCaption}{ }\end{DoxyParamCaption})}

reset all the encoder buttons to state zero released in the array 

Definition at line 144 of file emulator.\+cpp.

\mbox{\Hypertarget{emulator_8h_acb900d5f801949b0091609d85d37e25e}\label{emulator_8h_acb900d5f801949b0091609d85d37e25e}} 
\index{emulator.h@{emulator.h}!reset\_joy\_em@{reset\_joy\_em}}
\index{reset\_joy\_em@{reset\_joy\_em}!emulator.h@{emulator.h}}
\doxysubsubsection{\texorpdfstring{reset\_joy\_em()}{reset\_joy\_em()}}
{\footnotesize\ttfamily void reset\+\_\+joy\+\_\+em (\begin{DoxyParamCaption}{ }\end{DoxyParamCaption})}

reset the state of the emulated axes to center and buttons to not pressed 

Definition at line 86 of file emulator.\+cpp.

\mbox{\Hypertarget{emulator_8h_a38c47c0ebfb0a617625f431de7fb2de5}\label{emulator_8h_a38c47c0ebfb0a617625f431de7fb2de5}} 
\index{emulator.h@{emulator.h}!stop\_enc@{stop\_enc}}
\index{stop\_enc@{stop\_enc}!emulator.h@{emulator.h}}
\doxysubsubsection{\texorpdfstring{stop\_enc()}{stop\_enc()}}
{\footnotesize\ttfamily void stop\+\_\+enc (\begin{DoxyParamCaption}{ }\end{DoxyParamCaption})}

set encoders to center 

Definition at line 154 of file emulator.\+cpp.

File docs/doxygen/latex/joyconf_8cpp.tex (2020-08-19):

\hypertarget{joyconf_8cpp}{}\doxysection{C\+:/\+Users/mancio/\+Documents/\+V\+S\+Code/\+Fly\+Box2/src/joyconf.cpp File Reference}
\label{joyconf_8cpp}\index{C:/Users/mancio/Documents/VSCode/FlyBox2/src/joyconf.cpp@{C:/Users/mancio/Documents/VSCode/FlyBox2/src/joyconf.cpp}}
{\ttfamily \#include $<$Arduino.\+h$>$}\newline
{\ttfamily \#include $<$emulator.\+h$>$}\newline
{\ttfamily \#include $<$joyconf.\+h$>$}\newline
{\ttfamily \#include $<$Joystick.\+h$>$}\newline
{\ttfamily \#include $<$Pushbutton.\+h$>$}\newline
{\ttfamily \#include $<$C\+D74\+H\+C4067.\+h$>$}\newline
{\ttfamily \#include $<$ports.\+h$>$}\newline
{\ttfamily \#include $<$Timer.\+h$>$}\newline
{\ttfamily \#include $<$Encoders.\+h$>$}\newline
{\ttfamily \#include $<$Encoder.\+h$>$}\newline
\doxysubsection*{Macros}
\begin{DoxyCompactItemize}
\item 
\#define \mbox{\hyperlink{joyconf_8cpp_ac4708902f993b1914c265ec454377cb4}{totbt}}~16
\item 
\#define \mbox{\hyperlink{joyconf_8cpp_a54bdb80d23f9aa4a8a7eb910af7f6ccc}{left\+\_\+enc1\+\_\+bt}}~16
\item 
\#define \mbox{\hyperlink{joyconf_8cpp_ac357ad6d9c98ad04b83db7db2d165908}{right\+\_\+enc1\+\_\+bt}}~17
\item 
\#define \mbox{\hyperlink{joyconf_8cpp_a3a322d3d152d2f8696c1b150c5e59f5a}{left\+\_\+enc2\+\_\+bt}}~18
\item 
\#define \mbox{\hyperlink{joyconf_8cpp_a2bca6f9884f76cb907648b87c01f860e}{right\+\_\+enc2\+\_\+bt}}~19
\item 
\#define \mbox{\hyperlink{joyconf_8cpp_acee799f5f4bff7b803994c13287381e7}{left\+\_\+enc3\+\_\+bt}}~20
\item 
\#define \mbox{\hyperlink{joyconf_8cpp_aeff3e2daf3a25b146fe0653a9e2d2c17}{right\+\_\+enc3\+\_\+bt}}~21
\item 
\#define \mbox{\hyperlink{joyconf_8cpp_a37f8aaac363f801a21d34c4b81c1df07}{sw1\+\_\+bt}}~22
\item 
\#define \mbox{\hyperlink{joyconf_8cpp_ab50730ae357751c4341007c9a05a50cb}{sw2\+\_\+bt}}~23
\item 
\#define \mbox{\hyperlink{joyconf_8cpp_af2622f4e5f9d42e74d014d27c6967332}{sw3\+\_\+bt}}~24
\end{DoxyCompactItemize}
\doxysubsection*{Functions}
\begin{DoxyCompactItemize}
\item 
C\+D74\+H\+C4067 \mbox{\hyperlink{joyconf_8cpp_aff8cd1d42ca99f12b35e1cc2a1a2baae}{my\+\_\+mux}} (\mbox{\hyperlink{ports_8h_a5602e765893b26ac69ac6d13044cb7d0}{S0\+\_\+\+M\+UX}}, \mbox{\hyperlink{ports_8h_ac794a2a0f55f9bf2261f6b5c590e2854}{S1\+\_\+\+M\+UX}}, \mbox{\hyperlink{ports_8h_a2c5618db5c72aabdec31b3c03dc2cf8a}{S2\+\_\+\+M\+UX}}, \mbox{\hyperlink{ports_8h_a9b70c9282674eaf9a1e919ced0abdf32}{S3\+\_\+\+M\+UX}})
\item 
Joystick\+\_\+ \mbox{\hyperlink{joyconf_8cpp_a601497ba54038878634ed8327be11b3d}{Joystick}} (J\+O\+Y\+S\+T\+I\+C\+K\+\_\+\+D\+E\+F\+A\+U\+L\+T\+\_\+\+R\+E\+P\+O\+R\+T\+\_\+\+ID, J\+O\+Y\+S\+T\+I\+C\+K\+\_\+\+T\+Y\+P\+E\+\_\+\+J\+O\+Y\+S\+T\+I\+CK, 25, 0, true, true, true, false, false, false, false, false, false, false, false)
\item 
void \mbox{\hyperlink{joyconf_8cpp_afab08082007163b964f41ba8334b865a}{set\+Test}} (bool testin)
\item 
void \mbox{\hyperlink{joyconf_8cpp_aba818122d70d2c4ac723a578e75f7a3e}{joy\+\_\+conf}} ()
\item 
int \mbox{\hyperlink{joyconf_8cpp_af953debc945efa2555f04021970412cc}{debouncer}} (int button)
\item 
long \mbox{\hyperlink{joyconf_8cpp_a49cc520c407e8c57083155e620ed15d6}{mapper}} (long m, bool rev)
\item 
long \mbox{\hyperlink{joyconf_8cpp_aca616a67e14e1af19f4c36eedb9ae19d}{setX}} (int pin, bool rev)
\item 
long \mbox{\hyperlink{joyconf_8cpp_a68d0ce74156f4fb9ca09c7e738bcbf5b}{setY}} (int pin, bool rev)
\item 
long \mbox{\hyperlink{joyconf_8cpp_a4251eb0b20a921657f56758a51659964}{setZ}} (int pin, bool rev)
\item 
void \mbox{\hyperlink{joyconf_8cpp_ae830efa40aedd3af609d7ff5d406a782}{bt\+Array\+Filler}} ()
\item 
void \mbox{\hyperlink{joyconf_8cpp_a7fd8c17ec4e20e74986b3c51041f4026}{mux\+Looper}} ()
\item 
void \mbox{\hyperlink{joyconf_8cpp_a2b3557d5e92d039ce5744f99efe4efa2}{set\+Encoders\+\_\+dir}} ()
\end{DoxyCompactItemize}
\doxysubsection*{Variables}
\begin{DoxyCompactItemize}
\item 
\mbox{\hyperlink{class_encoders__}{Encoders\+\_\+}} \mbox{\hyperlink{joyconf_8cpp_af5d47d96437b0b65e80414f4787530ae}{Enc1}} (\mbox{\hyperlink{ports_8h_a2e4cc8cf6cec68902fb8a8829f338525}{C\+L\+K\+\_\+\+E\+N\+C\+\_\+1}}, \mbox{\hyperlink{ports_8h_a2907e00dc0a618e7b4789c8f6f81cf1a}{D\+T\+\_\+\+E\+N\+C\+\_\+1}}, \mbox{\hyperlink{ports_8h_acd9bd489eabbb4d0730686ca176fd024}{S\+W\+\_\+\+E\+N\+C\+\_\+1}})
\item 
\mbox{\hyperlink{class_encoders__}{Encoders\+\_\+}} \mbox{\hyperlink{joyconf_8cpp_a286f751c79038360c2679d1c318a2a9a}{Enc2}} (\mbox{\hyperlink{ports_8h_a6f67ffda52609be2b3a3950ea4b90525}{C\+L\+K\+\_\+\+E\+N\+C\+\_\+2}}, \mbox{\hyperlink{ports_8h_a90afd87f60a80e474659116675a51e1b}{D\+T\+\_\+\+E\+N\+C\+\_\+2}}, \mbox{\hyperlink{ports_8h_a6314e51358773be5a548e8bf3cda2be5}{S\+W\+\_\+\+E\+N\+C\+\_\+2}})
\item 
\mbox{\hyperlink{class_encoders__}{Encoders\+\_\+}} \mbox{\hyperlink{joyconf_8cpp_aeb707c96ab1bcc981fd379f564d9477f}{Enc3}} (\mbox{\hyperlink{ports_8h_abcddf50d66b91578ea092b61aa5b62ed}{C\+L\+K\+\_\+\+E\+N\+C\+\_\+3}}, \mbox{\hyperlink{ports_8h_a9a7d42fb916af7769b27e3cda7ec7863}{D\+T\+\_\+\+E\+N\+C\+\_\+3}}, \mbox{\hyperlink{ports_8h_aa9e570d5e2870b06b44d0b1859221e7f}{S\+W\+\_\+\+E\+N\+C\+\_\+3}})
\item 
int \mbox{\hyperlink{joyconf_8cpp_a9ce5bac15c5d149761370c579dded8ec}{joy\+\_\+bt\+\_\+array}} \mbox{[}\mbox{\hyperlink{joyconf_8cpp_ac4708902f993b1914c265ec454377cb4}{totbt}}\mbox{]}
\item 
\mbox{\hyperlink{class_timer__}{Timer\+\_\+}} \mbox{\hyperlink{joyconf_8cpp_ab386652564364fa6d88d7ab3a6c2289f}{Timer}}
\item 
long \mbox{\hyperlink{joyconf_8cpp_a2269c304870a359fe0ebcb1999580e9e}{t\+\_\+enc\+\_\+p}} = 10
\item 
long \mbox{\hyperlink{joyconf_8cpp_a4663849f4916930f3480059e92b86c7b}{t\+\_\+enc\+\_\+j}} = 10
\item 
\mbox{\hyperlink{class_button__}{Button\+\_\+}} \mbox{\hyperlink{joyconf_8cpp_a72323ac3c2ff74417b720a86f36f016d}{bt}} \mbox{[}\mbox{\hyperlink{joyconf_8cpp_ac4708902f993b1914c265ec454377cb4}{totbt}}\mbox{]}
\item 
int \mbox{\hyperlink{joyconf_8cpp_a5002611f83f5a861df12917dd5651db8}{button\+State}} = L\+OW
\item 
int \mbox{\hyperlink{joyconf_8cpp_a66f761d0471e843051f3c49af5a1cb82}{last\+Button\+State}} = L\+OW
\item 
int \mbox{\hyperlink{joyconf_8cpp_a5fa8d7fdcda2ed9555ad800a40a1a810}{reading}}
\item 
unsigned long \mbox{\hyperlink{joyconf_8cpp_a77d7d18f51343feebbe6d0eea7b4ac57}{debounce\+Delay}} = 100
\item 
bool \mbox{\hyperlink{joyconf_8cpp_a69f942d7289d5ed2ffe3a00b12235d04}{test}} = false
\end{DoxyCompactItemize}

\doxysubsection{Macro Definition Documentation}
\mbox{\Hypertarget{joyconf_8cpp_a54bdb80d23f9aa4a8a7eb910af7f6ccc}\label{joyconf_8cpp_a54bdb80d23f9aa4a8a7eb910af7f6ccc}} 
\index{joyconf.cpp@{joyconf.cpp}!left\_enc1\_bt@{left\_enc1\_bt}}
\index{left\_enc1\_bt@{left\_enc1\_bt}!joyconf.cpp@{joyconf.cpp}}
\doxysubsubsection{\texorpdfstring{left\_enc1\_bt}{left\_enc1\_bt}}
{\footnotesize\ttfamily \#define left\+\_\+enc1\+\_\+bt~16}

Definition at line 31 of file joyconf.\+cpp.

\mbox{\Hypertarget{joyconf_8cpp_a3a322d3d152d2f8696c1b150c5e59f5a}\label{joyconf_8cpp_a3a322d3d152d2f8696c1b150c5e59f5a}} 
\index{joyconf.cpp@{joyconf.cpp}!left\_enc2\_bt@{left\_enc2\_bt}}
\index{left\_enc2\_bt@{left\_enc2\_bt}!joyconf.cpp@{joyconf.cpp}}
\doxysubsubsection{\texorpdfstring{left\_enc2\_bt}{left\_enc2\_bt}}
{\footnotesize\ttfamily \#define left\+\_\+enc2\+\_\+bt~18}

Definition at line 33 of file joyconf.\+cpp.

\mbox{\Hypertarget{joyconf_8cpp_acee799f5f4bff7b803994c13287381e7}\label{joyconf_8cpp_acee799f5f4bff7b803994c13287381e7}} 
\index{joyconf.cpp@{joyconf.cpp}!left\_enc3\_bt@{left\_enc3\_bt}}
\index{left\_enc3\_bt@{left\_enc3\_bt}!joyconf.cpp@{joyconf.cpp}}
\doxysubsubsection{\texorpdfstring{left\_enc3\_bt}{left\_enc3\_bt}}
{\footnotesize\ttfamily \#define left\+\_\+enc3\+\_\+bt~20}

Definition at line 35 of file joyconf.\+cpp.

\mbox{\Hypertarget{joyconf_8cpp_ac357ad6d9c98ad04b83db7db2d165908}\label{joyconf_8cpp_ac357ad6d9c98ad04b83db7db2d165908}} 
\index{joyconf.cpp@{joyconf.cpp}!right\_enc1\_bt@{right\_enc1\_bt}}
\index{right\_enc1\_bt@{right\_enc1\_bt}!joyconf.cpp@{joyconf.cpp}}
\doxysubsubsection{\texorpdfstring{right\_enc1\_bt}{right\_enc1\_bt}}
{\footnotesize\ttfamily \#define right\+\_\+enc1\+\_\+bt~17}

Definition at line 32 of file joyconf.\+cpp.

\mbox{\Hypertarget{joyconf_8cpp_a2bca6f9884f76cb907648b87c01f860e}\label{joyconf_8cpp_a2bca6f9884f76cb907648b87c01f860e}} 
\index{joyconf.cpp@{joyconf.cpp}!right\_enc2\_bt@{right\_enc2\_bt}}
\index{right\_enc2\_bt@{right\_enc2\_bt}!joyconf.cpp@{joyconf.cpp}}
\doxysubsubsection{\texorpdfstring{right\_enc2\_bt}{right\_enc2\_bt}}
{\footnotesize\ttfamily \#define right\+\_\+enc2\+\_\+bt~19}

Definition at line 34 of file joyconf.\+cpp.

\mbox{\Hypertarget{joyconf_8cpp_aeff3e2daf3a25b146fe0653a9e2d2c17}\label{joyconf_8cpp_aeff3e2daf3a25b146fe0653a9e2d2c17}} 
\index{joyconf.cpp@{joyconf.cpp}!right\_enc3\_bt@{right\_enc3\_bt}}
\index{right\_enc3\_bt@{right\_enc3\_bt}!joyconf.cpp@{joyconf.cpp}}
\doxysubsubsection{\texorpdfstring{right\_enc3\_bt}{right\_enc3\_bt}}
{\footnotesize\ttfamily \#define right\+\_\+enc3\+\_\+bt~21}

Definition at line 36 of file joyconf.\+cpp.

\mbox{\Hypertarget{joyconf_8cpp_a37f8aaac363f801a21d34c4b81c1df07}\label{joyconf_8cpp_a37f8aaac363f801a21d34c4b81c1df07}} 
\index{joyconf.cpp@{joyconf.cpp}!sw1\_bt@{sw1\_bt}}
\index{sw1\_bt@{sw1\_bt}!joyconf.cpp@{joyconf.cpp}}
\doxysubsubsection{\texorpdfstring{sw1\_bt}{sw1\_bt}}
{\footnotesize\ttfamily \#define sw1\+\_\+bt~22}

Definition at line 38 of file joyconf.\+cpp.

\mbox{\Hypertarget{joyconf_8cpp_ab50730ae357751c4341007c9a05a50cb}\label{joyconf_8cpp_ab50730ae357751c4341007c9a05a50cb}} 
\index{joyconf.cpp@{joyconf.cpp}!sw2\_bt@{sw2\_bt}}
\index{sw2\_bt@{sw2\_bt}!joyconf.cpp@{joyconf.cpp}}
\doxysubsubsection{\texorpdfstring{sw2\_bt}{sw2\_bt}}
{\footnotesize\ttfamily \#define sw2\+\_\+bt~23}

Definition at line 39 of file joyconf.\+cpp.

\mbox{\Hypertarget{joyconf_8cpp_af2622f4e5f9d42e74d014d27c6967332}\label{joyconf_8cpp_af2622f4e5f9d42e74d014d27c6967332}} 
\index{joyconf.cpp@{joyconf.cpp}!sw3\_bt@{sw3\_bt}}
\index{sw3\_bt@{sw3\_bt}!joyconf.cpp@{joyconf.cpp}}
\doxysubsubsection{\texorpdfstring{sw3\_bt}{sw3\_bt}}
{\footnotesize\ttfamily \#define sw3\+\_\+bt~24}

Definition at line 40 of file joyconf.\+cpp.

\mbox{\Hypertarget{joyconf_8cpp_ac4708902f993b1914c265ec454377cb4}\label{joyconf_8cpp_ac4708902f993b1914c265ec454377cb4}} 
\index{joyconf.cpp@{joyconf.cpp}!totbt@{totbt}}
\index{totbt@{totbt}!joyconf.cpp@{joyconf.cpp}}
\doxysubsubsection{\texorpdfstring{totbt}{totbt}}
{\footnotesize\ttfamily \#define totbt~16}

Definition at line 29 of file joyconf.\+cpp.

\doxysubsection{Function Documentation}
\mbox{\Hypertarget{joyconf_8cpp_ae830efa40aedd3af609d7ff5d406a782}\label{joyconf_8cpp_ae830efa40aedd3af609d7ff5d406a782}} 
\index{joyconf.cpp@{joyconf.cpp}!btArrayFiller@{btArrayFiller}}
\index{btArrayFiller@{btArrayFiller}!joyconf.cpp@{joyconf.cpp}}
\doxysubsubsection{\texorpdfstring{btArrayFiller()}{btArrayFiller()}}
{\footnotesize\ttfamily void bt\+Array\+Filler (\begin{DoxyParamCaption}{ }\end{DoxyParamCaption})}

build an array of buttons in normal order from 1 to 16 

Definition at line 217 of file joyconf.\+cpp.

\mbox{\Hypertarget{joyconf_8cpp_af953debc945efa2555f04021970412cc}\label{joyconf_8cpp_af953debc945efa2555f04021970412cc}} 
\index{joyconf.cpp@{joyconf.cpp}!debouncer@{debouncer}}
\index{debouncer@{debouncer}!joyconf.cpp@{joyconf.cpp}}
\doxysubsubsection{\texorpdfstring{debouncer()}{debouncer()}}
{\footnotesize\ttfamily int debouncer (\begin{DoxyParamCaption}\item[{int}]{button }\end{DoxyParamCaption})}

debounce the click button (used in addiction with hardware debounce)

\begin{DoxyParams}{Parameters}
{\em int} & button to debounce \\
\hline
\end{DoxyParams}
\begin{DoxyReturn}{Returns}
button state debounced 
\end{DoxyReturn}

Definition at line 138 of file joyconf.\+cpp.

\mbox{\Hypertarget{joyconf_8cpp_aba818122d70d2c4ac723a578e75f7a3e}\label{joyconf_8cpp_aba818122d70d2c4ac723a578e75f7a3e}} 
\index{joyconf.cpp@{joyconf.cpp}!joy\_conf@{joy\_conf}}
\index{joy\_conf@{joy\_conf}!joyconf.cpp@{joyconf.cpp}}
\doxysubsubsection{\texorpdfstring{joy\_conf()}{joy\_conf()}}
{\footnotesize\ttfamily void joy\+\_\+conf (\begin{DoxyParamCaption}{ }\end{DoxyParamCaption})}

Initialize joystick library 

Definition at line 122 of file joyconf.\+cpp.

\mbox{\Hypertarget{joyconf_8cpp_a601497ba54038878634ed8327be11b3d}\label{joyconf_8cpp_a601497ba54038878634ed8327be11b3d}} 
\index{joyconf.cpp@{joyconf.cpp}!Joystick@{Joystick}}
\index{Joystick@{Joystick}!joyconf.cpp@{joyconf.cpp}}
\doxysubsubsection{\texorpdfstring{Joystick()}{Joystick()}}
{\footnotesize\ttfamily Joystick\+\_\+ Joystick (\begin{DoxyParamCaption}\item[{J\+O\+Y\+S\+T\+I\+C\+K\+\_\+\+D\+E\+F\+A\+U\+L\+T\+\_\+\+R\+E\+P\+O\+R\+T\+\_\+\+ID}]{,  }\item[{J\+O\+Y\+S\+T\+I\+C\+K\+\_\+\+T\+Y\+P\+E\+\_\+\+J\+O\+Y\+S\+T\+I\+CK}]{,  }\item[{25}]{,  }\item[{0}]{,  }\item[{true}]{,  }\item[{true}]{,  }\item[{true}]{,  }\item[{false}]{,  }\item[{false}]{,  }\item[{false}]{,  }\item[{false}]{,  }\item[{false}]{,  }\item[{false}]{,  }\item[{false}]{,  }\item[{false}]{ }\end{DoxyParamCaption})}

\mbox{\Hypertarget{joyconf_8cpp_a49cc520c407e8c57083155e620ed15d6}\label{joyconf_8cpp_a49cc520c407e8c57083155e620ed15d6}} 
\index{joyconf.cpp@{joyconf.cpp}!mapper@{mapper}}
\index{mapper@{mapper}!joyconf.cpp@{joyconf.cpp}}
\doxysubsubsection{\texorpdfstring{mapper()}{mapper()}}
{\footnotesize\ttfamily long mapper (\begin{DoxyParamCaption}\item[{long}]{m,  }\item[{bool}]{rev }\end{DoxyParamCaption})}

map the potentiometer scale to the Arduino analog input scale

\begin{DoxyParams}{Parameters}
{\em long} & input analog value from axis \\
\hline
{\em bool} & invert axis if false\\
\hline
\end{DoxyParams}
\begin{DoxyReturn}{Returns}
mapped value as long 
\end{DoxyReturn}

Definition at line 179 of file joyconf.\+cpp.

\mbox{\Hypertarget{joyconf_8cpp_a7fd8c17ec4e20e74986b3c51041f4026}\label{joyconf_8cpp_a7fd8c17ec4e20e74986b3c51041f4026}} 
\index{joyconf.cpp@{joyconf.cpp}!muxLooper@{muxLooper}}
\index{muxLooper@{muxLooper}!joyconf.cpp@{joyconf.cpp}}
\doxysubsubsection{\texorpdfstring{muxLooper()}{muxLooper()}}
{\footnotesize\ttfamily void mux\+Looper (\begin{DoxyParamCaption}{ }\end{DoxyParamCaption})}

loop the the multiplexer 16 pin connecting each of them to the S\+IG pin and write the input on the right joystick button. 

Definition at line 226 of file joyconf.\+cpp.

\mbox{\Hypertarget{joyconf_8cpp_aff8cd1d42ca99f12b35e1cc2a1a2baae}\label{joyconf_8cpp_aff8cd1d42ca99f12b35e1cc2a1a2baae}} 
\index{joyconf.cpp@{joyconf.cpp}!my\_mux@{my\_mux}}
\index{my\_mux@{my\_mux}!joyconf.cpp@{joyconf.cpp}}
\doxysubsubsection{\texorpdfstring{my\_mux()}{my\_mux()}}
{\footnotesize\ttfamily C\+D74\+H\+C4067 my\+\_\+mux (\begin{DoxyParamCaption}\item[{\mbox{\hyperlink{ports_8h_a5602e765893b26ac69ac6d13044cb7d0}{S0\+\_\+\+M\+UX}}}]{,  }\item[{\mbox{\hyperlink{ports_8h_ac794a2a0f55f9bf2261f6b5c590e2854}{S1\+\_\+\+M\+UX}}}]{,  }\item[{\mbox{\hyperlink{ports_8h_a2c5618db5c72aabdec31b3c03dc2cf8a}{S2\+\_\+\+M\+UX}}}]{,  }\item[{\mbox{\hyperlink{ports_8h_a9b70c9282674eaf9a1e919ced0abdf32}{S3\+\_\+\+M\+UX}}}]{ }\end{DoxyParamCaption})}

\mbox{\Hypertarget{joyconf_8cpp_a2b3557d5e92d039ce5744f99efe4efa2}\label{joyconf_8cpp_a2b3557d5e92d039ce5744f99efe4efa2}} 
\index{joyconf.cpp@{joyconf.cpp}!setEncoders\_dir@{setEncoders\_dir}}
\index{setEncoders\_dir@{setEncoders\_dir}!joyconf.cpp@{joyconf.cpp}}
\doxysubsubsection{\texorpdfstring{setEncoders\_dir()}{setEncoders\_dir()}}
{\footnotesize\ttfamily void set\+Encoders\+\_\+dir (\begin{DoxyParamCaption}{ }\end{DoxyParamCaption})}

push buttons depending by encoders direction and click buttons 

Definition at line 242 of file joyconf.\+cpp.

\mbox{\Hypertarget{joyconf_8cpp_afab08082007163b964f41ba8334b865a}\label{joyconf_8cpp_afab08082007163b964f41ba8334b865a}} 
\index{joyconf.cpp@{joyconf.cpp}!setTest@{setTest}}
\index{setTest@{setTest}!joyconf.cpp@{joyconf.cpp}}
\doxysubsubsection{\texorpdfstring{setTest()}{setTest()}}
{\footnotesize\ttfamily void set\+Test (\begin{DoxyParamCaption}\item[{bool}]{testin }\end{DoxyParamCaption})}

set the execution in test mode

\begin{DoxyParams}{Parameters}
{\em bool} & if true test mode, if false normal mode \\
\hline
\end{DoxyParams}

Definition at line 118 of file joyconf.\+cpp.

\mbox{\Hypertarget{joyconf_8cpp_aca616a67e14e1af19f4c36eedb9ae19d}\label{joyconf_8cpp_aca616a67e14e1af19f4c36eedb9ae19d}} 
\index{joyconf.cpp@{joyconf.cpp}!setX@{setX}}
\index{setX@{setX}!joyconf.cpp@{joyconf.cpp}}
\doxysubsubsection{\texorpdfstring{setX()}{setX()}}
{\footnotesize\ttfamily long setX (\begin{DoxyParamCaption}\item[{int}]{pin,  }\item[{bool}]{rev }\end{DoxyParamCaption})}

check and set X-\/axis input value

\begin{DoxyParams}{Parameters}
{\em int} & pin number \\
\hline
{\em bool} & if false reverse the axis\\
\hline
\end{DoxyParams}
\begin{DoxyReturn}{Returns}
long axis value 
\end{DoxyReturn}

Definition at line 187 of file joyconf.\+cpp.

\mbox{\Hypertarget{joyconf_8cpp_a68d0ce74156f4fb9ca09c7e738bcbf5b}\label{joyconf_8cpp_a68d0ce74156f4fb9ca09c7e738bcbf5b}} 
\index{joyconf.cpp@{joyconf.cpp}!setY@{setY}}
\index{setY@{setY}!joyconf.cpp@{joyconf.cpp}}
\doxysubsubsection{\texorpdfstring{setY()}{setY()}}
{\footnotesize\ttfamily long setY (\begin{DoxyParamCaption}\item[{int}]{pin,  }\item[{bool}]{rev }\end{DoxyParamCaption})}

check and set Y-\/axis input value

\begin{DoxyParams}{Parameters}
{\em int} & pin number \\
\hline
{\em bool} & if false reverse the axis\\
\hline
\end{DoxyParams}
\begin{DoxyReturn}{Returns}
long axis value 
\end{DoxyReturn}

Definition at line 197 of file joyconf.\+cpp.

\mbox{\Hypertarget{joyconf_8cpp_a4251eb0b20a921657f56758a51659964}\label{joyconf_8cpp_a4251eb0b20a921657f56758a51659964}} 
\index{joyconf.cpp@{joyconf.cpp}!setZ@{setZ}}
\index{setZ@{setZ}!joyconf.cpp@{joyconf.cpp}}
\doxysubsubsection{\texorpdfstring{setZ()}{setZ()}}
{\footnotesize\ttfamily long setZ (\begin{DoxyParamCaption}\item[{int}]{pin,  }\item[{bool}]{rev }\end{DoxyParamCaption})}

check and set Z-\/axis input value

\begin{DoxyParams}{Parameters}
{\em int} & pin number \\
\hline
{\em bool} & if false reverse the axis\\
\hline
\end{DoxyParams}
\begin{DoxyReturn}{Returns}
long axis value 
\end{DoxyReturn}

Definition at line 207 of file joyconf.\+cpp.

\doxysubsection{Variable Documentation}
\mbox{\Hypertarget{joyconf_8cpp_a72323ac3c2ff74417b720a86f36f016d}\label{joyconf_8cpp_a72323ac3c2ff74417b720a86f36f016d}} 
\index{joyconf.cpp@{joyconf.cpp}!bt@{bt}}
\index{bt@{bt}!joyconf.cpp@{joyconf.cpp}}
\doxysubsubsection{\texorpdfstring{bt}{bt}}
{\footnotesize\ttfamily \mbox{\hyperlink{class_button__}{Button\+\_\+}} bt\mbox{[}\mbox{\hyperlink{joyconf_8cpp_ac4708902f993b1914c265ec454377cb4}{totbt}}\mbox{]}}

Definition at line 98 of file joyconf.\+cpp.

\mbox{\Hypertarget{joyconf_8cpp_a5002611f83f5a861df12917dd5651db8}\label{joyconf_8cpp_a5002611f83f5a861df12917dd5651db8}} 
\index{joyconf.cpp@{joyconf.cpp}!buttonState@{buttonState}}
\index{buttonState@{buttonState}!joyconf.cpp@{joyconf.cpp}}
\doxysubsubsection{\texorpdfstring{buttonState}{buttonState}}
{\footnotesize\ttfamily int button\+State = L\+OW}

Definition at line 101 of file joyconf.\+cpp.

\mbox{\Hypertarget{joyconf_8cpp_a77d7d18f51343feebbe6d0eea7b4ac57}\label{joyconf_8cpp_a77d7d18f51343feebbe6d0eea7b4ac57}} 
\index{joyconf.cpp@{joyconf.cpp}!debounceDelay@{debounceDelay}}
\index{debounceDelay@{debounceDelay}!joyconf.cpp@{joyconf.cpp}}
\doxysubsubsection{\texorpdfstring{debounceDelay}{debounceDelay}}
{\footnotesize\ttfamily unsigned long debounce\+Delay = 100}

Definition at line 113 of file joyconf.\+cpp.

\mbox{\Hypertarget{joyconf_8cpp_af5d47d96437b0b65e80414f4787530ae}\label{joyconf_8cpp_af5d47d96437b0b65e80414f4787530ae}} 
\index{joyconf.cpp@{joyconf.cpp}!Enc1@{Enc1}}
\index{Enc1@{Enc1}!joyconf.cpp@{joyconf.cpp}}
\doxysubsubsection{\texorpdfstring{Enc1}{Enc1}}
{\footnotesize\ttfamily \mbox{\hyperlink{class_encoders__}{Encoders\+\_\+}} Enc1(\mbox{\hyperlink{ports_8h_a2e4cc8cf6cec68902fb8a8829f338525}{C\+L\+K\+\_\+\+E\+N\+C\+\_\+1}}, \mbox{\hyperlink{ports_8h_a2907e00dc0a618e7b4789c8f6f81cf1a}{D\+T\+\_\+\+E\+N\+C\+\_\+1}}, \mbox{\hyperlink{ports_8h_acd9bd489eabbb4d0730686ca176fd024}{S\+W\+\_\+\+E\+N\+C\+\_\+1}})}

\mbox{\Hypertarget{joyconf_8cpp_a286f751c79038360c2679d1c318a2a9a}\label{joyconf_8cpp_a286f751c79038360c2679d1c318a2a9a}} 
\index{joyconf.cpp@{joyconf.cpp}!Enc2@{Enc2}}
\index{Enc2@{Enc2}!joyconf.cpp@{joyconf.cpp}}
\doxysubsubsection{\texorpdfstring{Enc2}{Enc2}}
{\footnotesize\ttfamily \mbox{\hyperlink{class_encoders__}{Encoders\+\_\+}} Enc2(\mbox{\hyperlink{ports_8h_a6f67ffda52609be2b3a3950ea4b90525}{C\+L\+K\+\_\+\+E\+N\+C\+\_\+2}}, \mbox{\hyperlink{ports_8h_a90afd87f60a80e474659116675a51e1b}{D\+T\+\_\+\+E\+N\+C\+\_\+2}}, \mbox{\hyperlink{ports_8h_a6314e51358773be5a548e8bf3cda2be5}{S\+W\+\_\+\+E\+N\+C\+\_\+2}})}

\mbox{\Hypertarget{joyconf_8cpp_aeb707c96ab1bcc981fd379f564d9477f}\label{joyconf_8cpp_aeb707c96ab1bcc981fd379f564d9477f}} 
\index{joyconf.cpp@{joyconf.cpp}!Enc3@{Enc3}}
\index{Enc3@{Enc3}!joyconf.cpp@{joyconf.cpp}}
\doxysubsubsection{\texorpdfstring{Enc3}{Enc3}}
{\footnotesize\ttfamily \mbox{\hyperlink{class_encoders__}{Encoders\+\_\+}} Enc3(\mbox{\hyperlink{ports_8h_abcddf50d66b91578ea092b61aa5b62ed}{C\+L\+K\+\_\+\+E\+N\+C\+\_\+3}}, \mbox{\hyperlink{ports_8h_a9a7d42fb916af7769b27e3cda7ec7863}{D\+T\+\_\+\+E\+N\+C\+\_\+3}}, \mbox{\hyperlink{ports_8h_aa9e570d5e2870b06b44d0b1859221e7f}{S\+W\+\_\+\+E\+N\+C\+\_\+3}})}

\mbox{\Hypertarget{joyconf_8cpp_a9ce5bac15c5d149761370c579dded8ec}\label{joyconf_8cpp_a9ce5bac15c5d149761370c579dded8ec}} 
\index{joyconf.cpp@{joyconf.cpp}!joy\_bt\_array@{joy\_bt\_array}}
\index{joy\_bt\_array@{joy\_bt\_array}!joyconf.cpp@{joyconf.cpp}}
\doxysubsubsection{\texorpdfstring{joy\_bt\_array}{joy\_bt\_array}}
{\footnotesize\ttfamily int joy\+\_\+bt\+\_\+array\mbox{[}\mbox{\hyperlink{joyconf_8cpp_ac4708902f993b1914c265ec454377cb4}{totbt}}\mbox{]}}

Definition at line 65 of file joyconf.\+cpp.

\mbox{\Hypertarget{joyconf_8cpp_a66f761d0471e843051f3c49af5a1cb82}\label{joyconf_8cpp_a66f761d0471e843051f3c49af5a1cb82}} 
\index{joyconf.cpp@{joyconf.cpp}!lastButtonState@{lastButtonState}}
\index{lastButtonState@{lastButtonState}!joyconf.cpp@{joyconf.cpp}}
\doxysubsubsection{\texorpdfstring{lastButtonState}{lastButtonState}}
{\footnotesize\ttfamily int last\+Button\+State = L\+OW}

Definition at line 103 of file joyconf.\+cpp.

\mbox{\Hypertarget{joyconf_8cpp_a5fa8d7fdcda2ed9555ad800a40a1a810}\label{joyconf_8cpp_a5fa8d7fdcda2ed9555ad800a40a1a810}} 
\index{joyconf.cpp@{joyconf.cpp}!reading@{reading}}
\index{reading@{reading}!joyconf.cpp@{joyconf.cpp}}
\doxysubsubsection{\texorpdfstring{reading}{reading}}
{\footnotesize\ttfamily int reading}

Definition at line 106 of file joyconf.\+cpp.

\mbox{\Hypertarget{joyconf_8cpp_a4663849f4916930f3480059e92b86c7b}\label{joyconf_8cpp_a4663849f4916930f3480059e92b86c7b}} 
\index{joyconf.cpp@{joyconf.cpp}!t\_enc\_j@{t\_enc\_j}}
\index{t\_enc\_j@{t\_enc\_j}!joyconf.cpp@{joyconf.cpp}}
\doxysubsubsection{\texorpdfstring{t\_enc\_j}{t\_enc\_j}}
{\footnotesize\ttfamily long t\+\_\+enc\+\_\+j = 10}

Definition at line 74 of file joyconf.\+cpp.

\mbox{\Hypertarget{joyconf_8cpp_a2269c304870a359fe0ebcb1999580e9e}\label{joyconf_8cpp_a2269c304870a359fe0ebcb1999580e9e}} 
\index{joyconf.cpp@{joyconf.cpp}!t\_enc\_p@{t\_enc\_p}}
\index{t\_enc\_p@{t\_enc\_p}!joyconf.cpp@{joyconf.cpp}}
\doxysubsubsection{\texorpdfstring{t\_enc\_p}{t\_enc\_p}}
{\footnotesize\ttfamily long t\+\_\+enc\+\_\+p = 10}

Definition at line 71 of file joyconf.\+cpp.

\mbox{\Hypertarget{joyconf_8cpp_a69f942d7289d5ed2ffe3a00b12235d04}\label{joyconf_8cpp_a69f942d7289d5ed2ffe3a00b12235d04}} 
\index{joyconf.cpp@{joyconf.cpp}!test@{test}}
\index{test@{test}!joyconf.cpp@{joyconf.cpp}}
\doxysubsubsection{\texorpdfstring{test}{test}}
{\footnotesize\ttfamily bool test = false}

Definition at line 116 of file joyconf.\+cpp.

\mbox{\Hypertarget{joyconf_8cpp_ab386652564364fa6d88d7ab3a6c2289f}\label{joyconf_8cpp_ab386652564364fa6d88d7ab3a6c2289f}} 
\index{joyconf.cpp@{joyconf.cpp}!Timer@{Timer}}
\index{Timer@{Timer}!joyconf.cpp@{joyconf.cpp}}
\doxysubsubsection{\texorpdfstring{Timer}{Timer}}
{\footnotesize\ttfamily \mbox{\hyperlink{class_timer__}{Timer\+\_\+}} Timer}

Definition at line 68 of file joyconf.\+cpp.

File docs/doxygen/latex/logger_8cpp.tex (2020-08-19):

\hypertarget{logger_8cpp}{}\doxysection{C\+:/\+Users/mancio/\+Documents/\+V\+S\+Code/\+Fly\+Box2/src/logger.cpp File Reference}
\label{logger_8cpp}\index{C:/Users/mancio/Documents/VSCode/FlyBox2/src/logger.cpp@{C:/Users/mancio/Documents/VSCode/FlyBox2/src/logger.cpp}}
{\ttfamily \#include $<$Arduino.\+h$>$}\newline
\doxysubsection*{Functions}
\begin{DoxyCompactItemize}
\item 
void \mbox{\hyperlink{logger_8cpp_a77225f99a5023842a36dae1953e32e1e}{log\+\_\+ax}} (long x\+\_\+p, long y\+\_\+p, long z\+\_\+p)
\end{DoxyCompactItemize}

\doxysubsection{Function Documentation}
\mbox{\Hypertarget{logger_8cpp_a77225f99a5023842a36dae1953e32e1e}\label{logger_8cpp_a77225f99a5023842a36dae1953e32e1e}} 
\index{logger.cpp@{logger.cpp}!log\_ax@{log\_ax}}
\index{log\_ax@{log\_ax}!logger.cpp@{logger.cpp}}
\doxysubsubsection{\texorpdfstring{log\_ax()}{log\_ax()}}
{\footnotesize\ttfamily void log\+\_\+ax (\begin{DoxyParamCaption}\item[{long}]{x\+\_\+p,  }\item[{long}]{y\+\_\+p,  }\item[{long}]{z\+\_\+p }\end{DoxyParamCaption})}

serial print the axes position

\begin{DoxyParams}{Parameters}
{\em x} & asis \\
\hline
{\em y} & axis \\
\hline
{\em z} & axis \\
\hline
\end{DoxyParams}

Definition at line 24 of file logger.\+cpp.

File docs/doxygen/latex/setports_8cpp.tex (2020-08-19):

\hypertarget{setports_8cpp}{}\doxysection{C\+:/\+Users/mancio/\+Documents/\+V\+S\+Code/\+Fly\+Box2/src/setports.cpp File Reference}
\label{setports_8cpp}\index{C:/Users/mancio/Documents/VSCode/FlyBox2/src/setports.cpp@{C:/Users/mancio/Documents/VSCode/FlyBox2/src/setports.cpp}}
{\ttfamily \#include $<$Arduino.\+h$>$}\newline
{\ttfamily \#include $<$setports.\+h$>$}\newline
{\ttfamily \#include $<$ports.\+h$>$}\newline
\doxysubsection*{Functions}
\begin{DoxyCompactItemize}
\item 
void \mbox{\hyperlink{setports_8cpp_a5f05229b58d8580b5a05d5ee2fdaf358}{active\+Serial}} ()
\item 
void \mbox{\hyperlink{setports_8cpp_a90d6ff9b3f06524e1315f260d0c35d4c}{set\+Encoders}} ()
\item 
void \mbox{\hyperlink{setports_8cpp_a1c1372335213cc7bad3e80c5c652f9d0}{set\+Pot}} ()
\item 
void \mbox{\hyperlink{setports_8cpp_aeb5405c9aed4372d21fb6b465f4a2df1}{set\+Mux}} ()
\end{DoxyCompactItemize}

\doxysubsection{Function Documentation}
\mbox{\Hypertarget{setports_8cpp_a5f05229b58d8580b5a05d5ee2fdaf358}\label{setports_8cpp_a5f05229b58d8580b5a05d5ee2fdaf358}} 
\index{setports.cpp@{setports.cpp}!activeSerial@{activeSerial}}
\index{activeSerial@{activeSerial}!setports.cpp@{setports.cpp}}
\doxysubsubsection{\texorpdfstring{activeSerial()}{activeSerial()}}
{\footnotesize\ttfamily void active\+Serial (\begin{DoxyParamCaption}{ }\end{DoxyParamCaption})}

active serial port on Arduino 

Definition at line 28 of file setports.\+cpp.

\mbox{\Hypertarget{setports_8cpp_a90d6ff9b3f06524e1315f260d0c35d4c}\label{setports_8cpp_a90d6ff9b3f06524e1315f260d0c35d4c}} 
\index{setports.cpp@{setports.cpp}!setEncoders@{setEncoders}}
\index{setEncoders@{setEncoders}!setports.cpp@{setports.cpp}}
\doxysubsubsection{\texorpdfstring{setEncoders()}{setEncoders()}}
{\footnotesize\ttfamily void set\+Encoders (\begin{DoxyParamCaption}{ }\end{DoxyParamCaption})}

set encoder ports 

Definition at line 33 of file setports.\+cpp.

\mbox{\Hypertarget{setports_8cpp_aeb5405c9aed4372d21fb6b465f4a2df1}\label{setports_8cpp_aeb5405c9aed4372d21fb6b465f4a2df1}} 
\index{setports.cpp@{setports.cpp}!setMux@{setMux}}
\index{setMux@{setMux}!setports.cpp@{setports.cpp}}
\doxysubsubsection{\texorpdfstring{setMux()}{setMux()}}
{\footnotesize\ttfamily void set\+Mux (\begin{DoxyParamCaption}{ }\end{DoxyParamCaption})}

set multiplexer ports 

Definition at line 58 of file setports.\+cpp.

\mbox{\Hypertarget{setports_8cpp_a1c1372335213cc7bad3e80c5c652f9d0}\label{setports_8cpp_a1c1372335213cc7bad3e80c5c652f9d0}} 
\index{setports.cpp@{setports.cpp}!setPot@{setPot}}
\index{setPot@{setPot}!setports.cpp@{setports.cpp}}
\doxysubsubsection{\texorpdfstring{setPot()}{setPot()}}
{\footnotesize\ttfamily void set\+Pot (\begin{DoxyParamCaption}{ }\end{DoxyParamCaption})}

set slide potentiometers analog input ports 

Definition at line 51 of file setports.\+cpp.

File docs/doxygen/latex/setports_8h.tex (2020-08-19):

\hypertarget{setports_8h}{}\doxysection{C\+:/\+Users/mancio/\+Documents/\+V\+S\+Code/\+Fly\+Box2/include/setports.h File Reference}
\label{setports_8h}\index{C:/Users/mancio/Documents/VSCode/FlyBox2/include/setports.h@{C:/Users/mancio/Documents/VSCode/FlyBox2/include/setports.h}}
{\ttfamily \#include $<$Arduino.\+h$>$}\newline
\doxysubsection*{Functions}
\begin{DoxyCompactItemize}
\item 
void \mbox{\hyperlink{setports_8h_a5f05229b58d8580b5a05d5ee2fdaf358}{active\+Serial}} ()
\item 
void \mbox{\hyperlink{setports_8h_a90d6ff9b3f06524e1315f260d0c35d4c}{set\+Encoders}} ()
\item 
void \mbox{\hyperlink{setports_8h_a1c1372335213cc7bad3e80c5c652f9d0}{set\+Pot}} ()
\item 
void \mbox{\hyperlink{setports_8h_aeb5405c9aed4372d21fb6b465f4a2df1}{set\+Mux}} ()
\end{DoxyCompactItemize}

\doxysubsection{Function Documentation}
\mbox{\Hypertarget{setports_8h_a5f05229b58d8580b5a05d5ee2fdaf358}\label{setports_8h_a5f05229b58d8580b5a05d5ee2fdaf358}} 
\index{setports.h@{setports.h}!activeSerial@{activeSerial}}
\index{activeSerial@{activeSerial}!setports.h@{setports.h}}
\doxysubsubsection{\texorpdfstring{activeSerial()}{activeSerial()}}
{\footnotesize\ttfamily void active\+Serial (\begin{DoxyParamCaption}{ }\end{DoxyParamCaption})}

active serial port on Arduino 

Definition at line 28 of file setports.\+cpp.

\mbox{\Hypertarget{setports_8h_a90d6ff9b3f06524e1315f260d0c35d4c}\label{setports_8h_a90d6ff9b3f06524e1315f260d0c35d4c}} 
\index{setports.h@{setports.h}!setEncoders@{setEncoders}}
\index{setEncoders@{setEncoders}!setports.h@{setports.h}}
\doxysubsubsection{\texorpdfstring{setEncoders()}{setEncoders()}}
{\footnotesize\ttfamily void set\+Encoders (\begin{DoxyParamCaption}{ }\end{DoxyParamCaption})}

set encoder ports 

Definition at line 33 of file setports.\+cpp.

\mbox{\Hypertarget{setports_8h_aeb5405c9aed4372d21fb6b465f4a2df1}\label{setports_8h_aeb5405c9aed4372d21fb6b465f4a2df1}} 
\index{setports.h@{setports.h}!setMux@{setMux}}
\index{setMux@{setMux}!setports.h@{setports.h}}
\doxysubsubsection{\texorpdfstring{setMux()}{setMux()}}
{\footnotesize\ttfamily void set\+Mux (\begin{DoxyParamCaption}{ }\end{DoxyParamCaption})}

set multiplexer ports 

Definition at line 58 of file setports.\+cpp.

\mbox{\Hypertarget{setports_8h_a1c1372335213cc7bad3e80c5c652f9d0}\label{setports_8h_a1c1372335213cc7bad3e80c5c652f9d0}} 
\index{setports.h@{setports.h}!setPot@{setPot}}
\index{setPot@{setPot}!setports.h@{setports.h}}
\doxysubsubsection{\texorpdfstring{setPot()}{setPot()}}
{\footnotesize\ttfamily void set\+Pot (\begin{DoxyParamCaption}{ }\end{DoxyParamCaption})}

set slide potentiometers analog input ports 

Definition at line 51 of file setports.\+cpp.

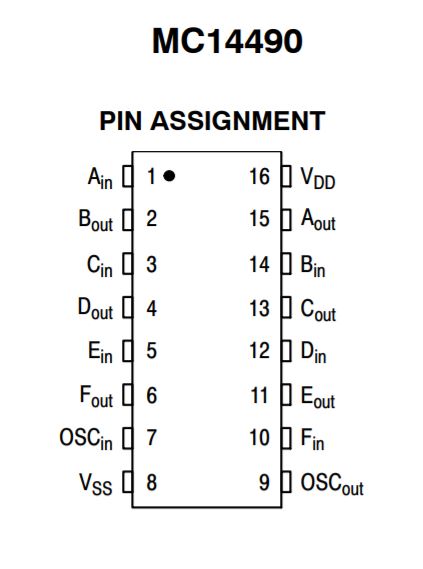
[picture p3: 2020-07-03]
AltiumProject/componets/MC14490-D_pinout.JPG

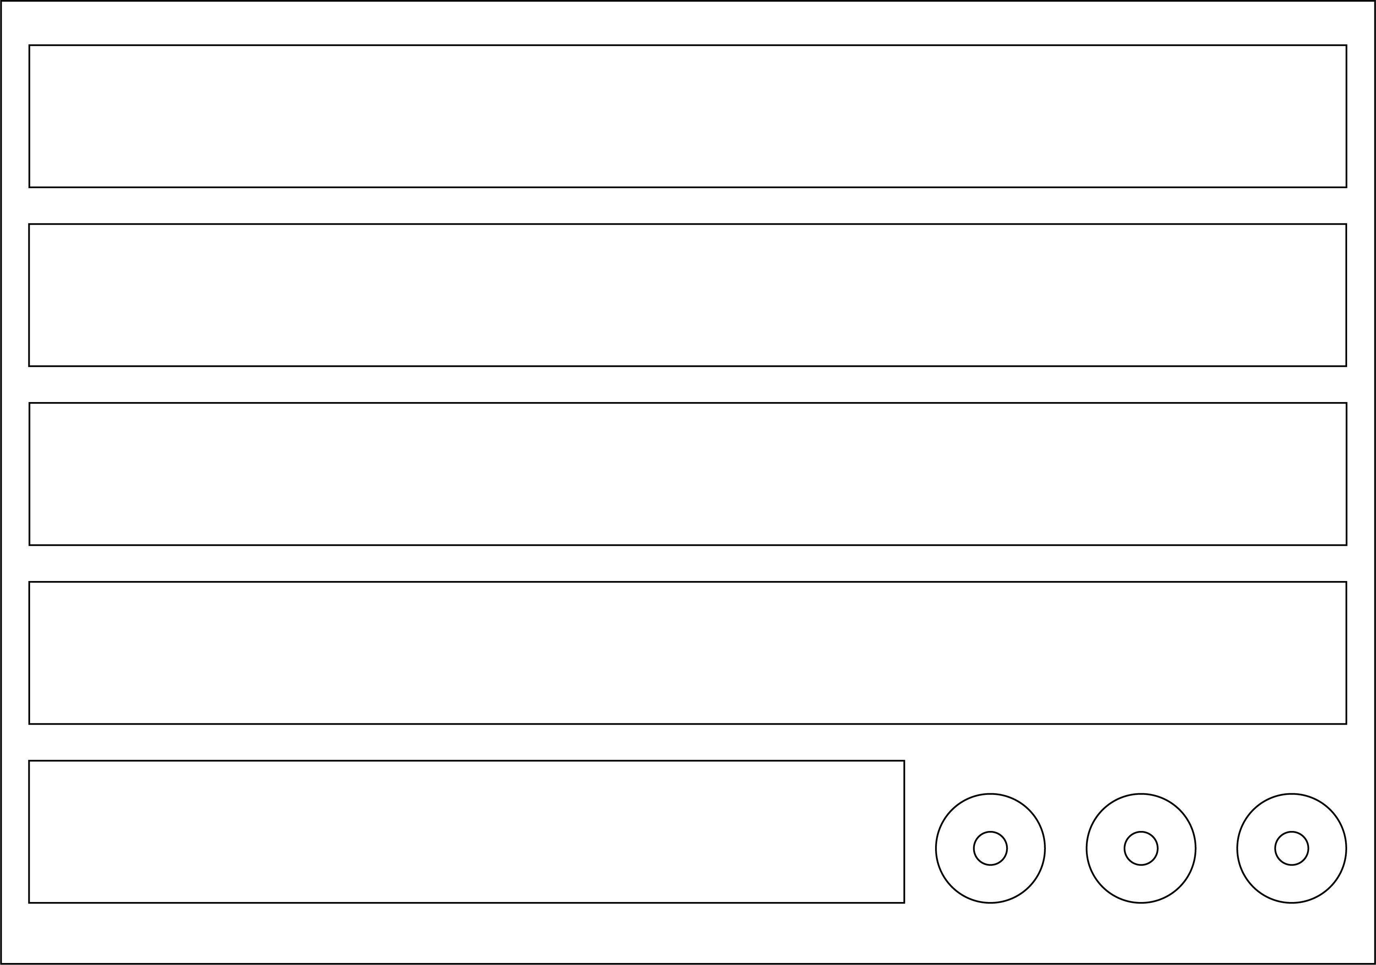
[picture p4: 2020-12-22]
artdesign/side_stripe.jpg

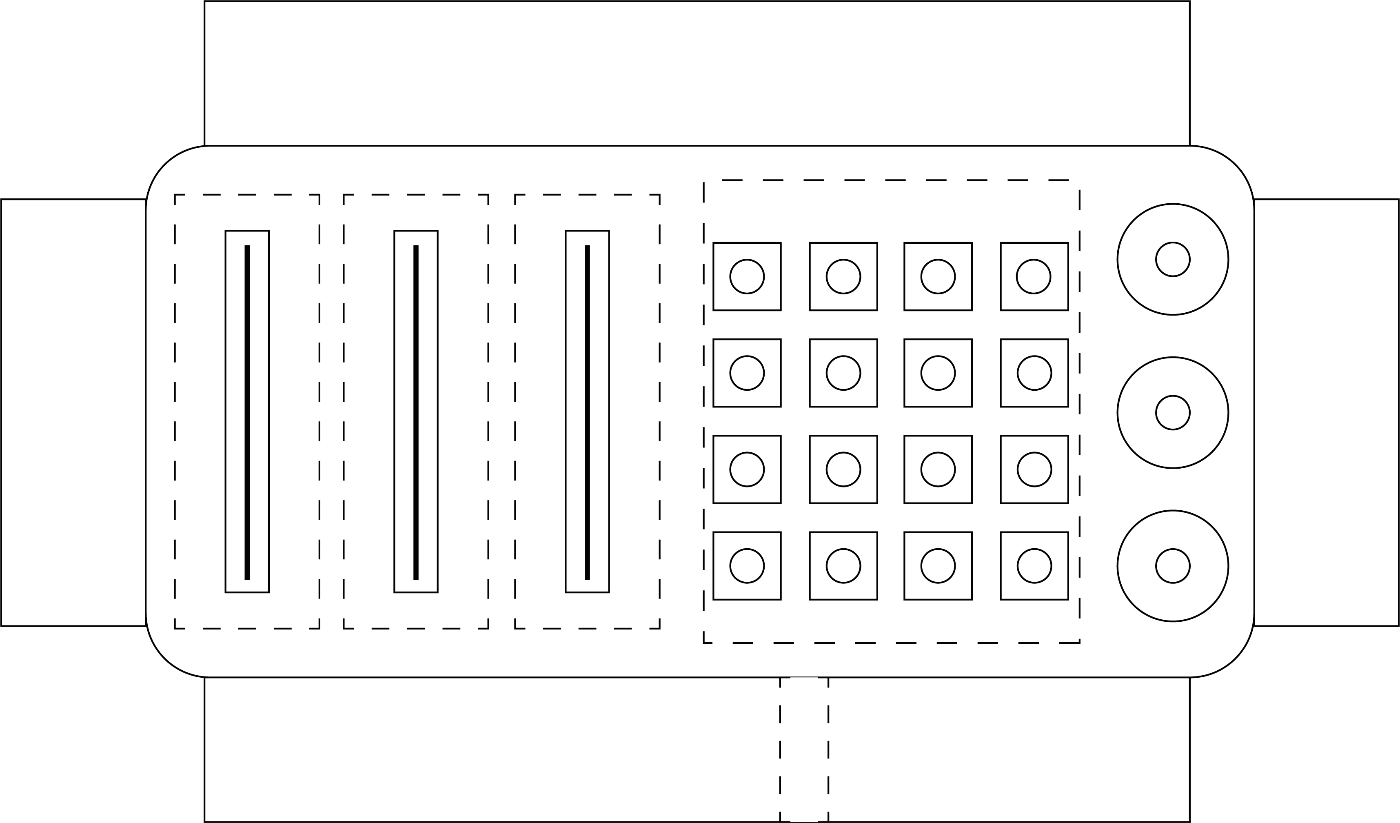
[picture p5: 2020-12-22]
artdesign/front.jpg

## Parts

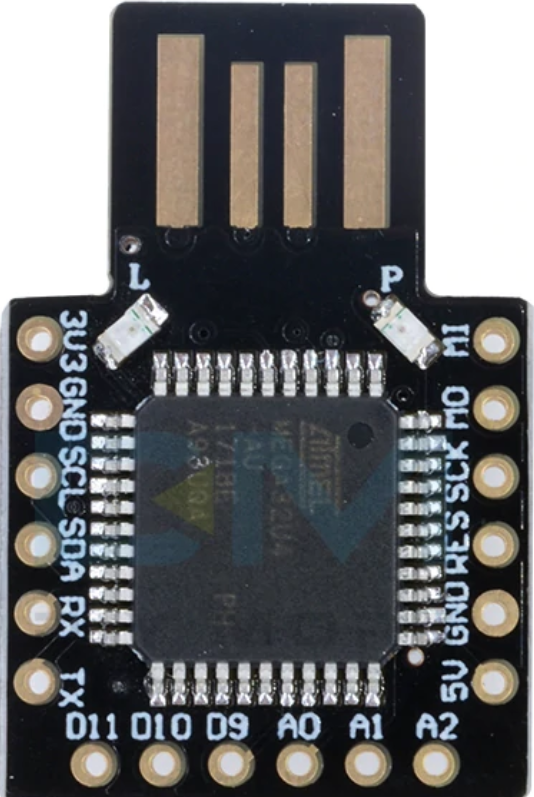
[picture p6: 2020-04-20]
fritzing/parts/Beetle_Micro_USB_ATMEGA32U4.PNG

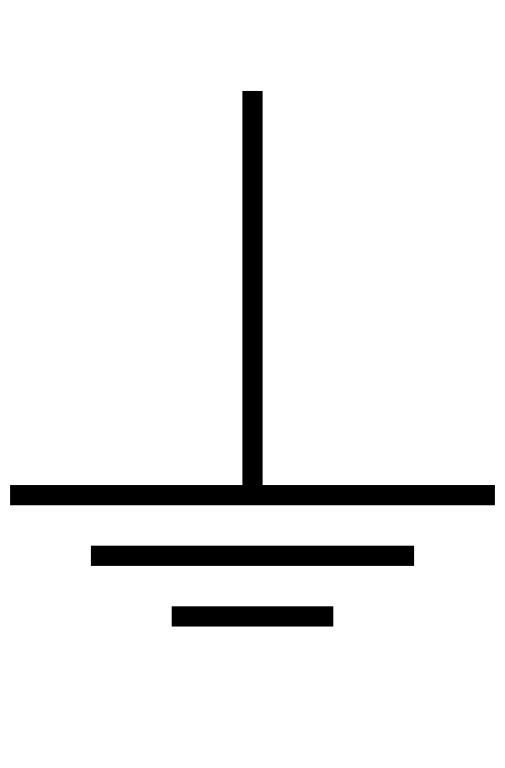
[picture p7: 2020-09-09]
fritzing/parts/505px-Earth_Ground.svg.png

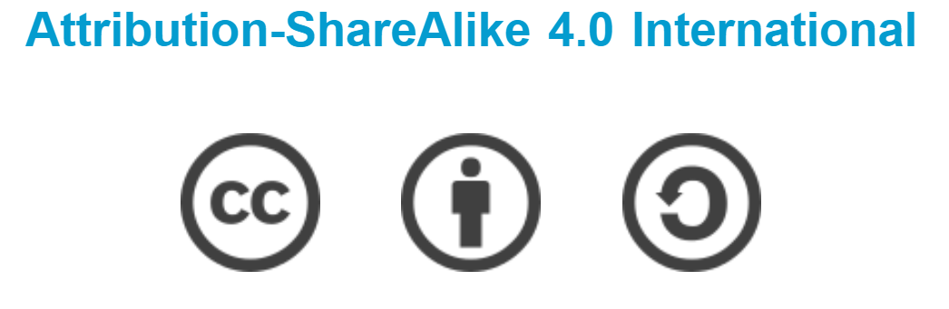
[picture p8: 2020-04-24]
fritzing/parts/CCShareAlike.PNG

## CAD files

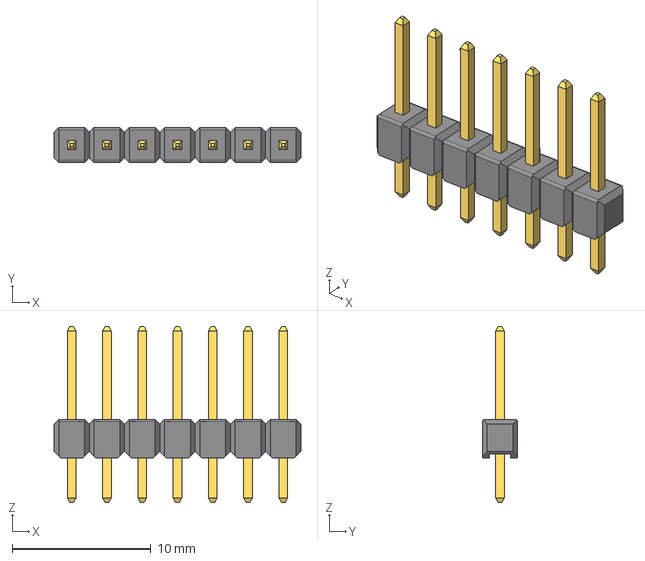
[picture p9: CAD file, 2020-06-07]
AltiumProject/componets/Pin Header 1x7 TH Pitch 2.54mm.stp
17.8 x 2.54 x 12.7 mm

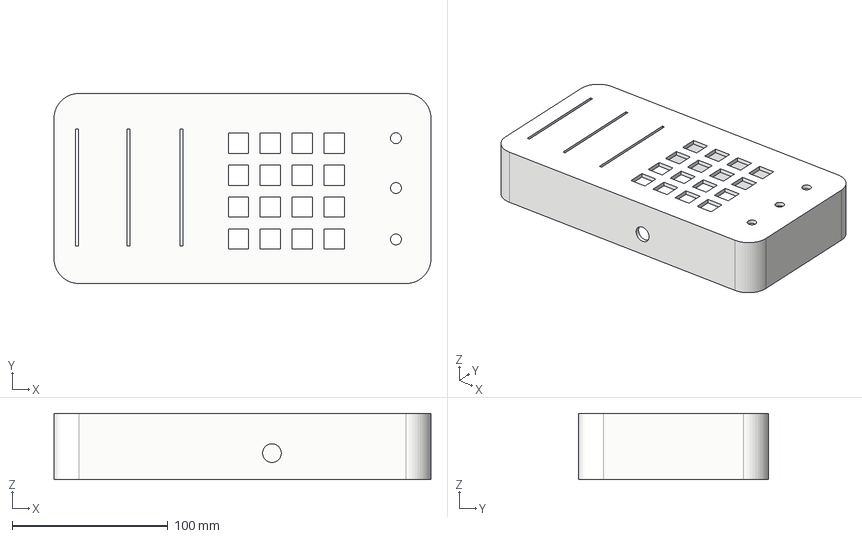
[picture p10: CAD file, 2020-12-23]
artdesign/fusion360/CaseForPrint.step
242.0 x 122.0 x 42.4 mm

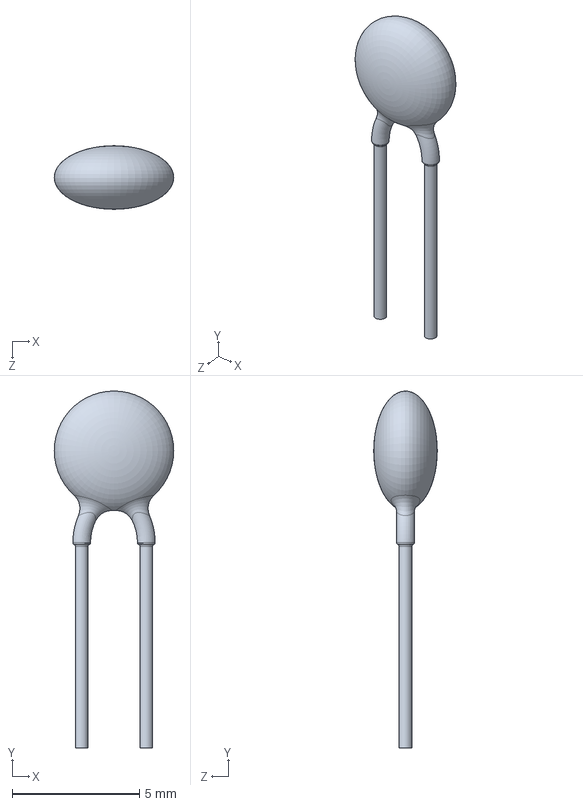
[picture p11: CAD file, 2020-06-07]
AltiumProject/componets/10pF Ceramic Disc 2.SLDPRT
4.70 x 14.0 x 2.50 mm

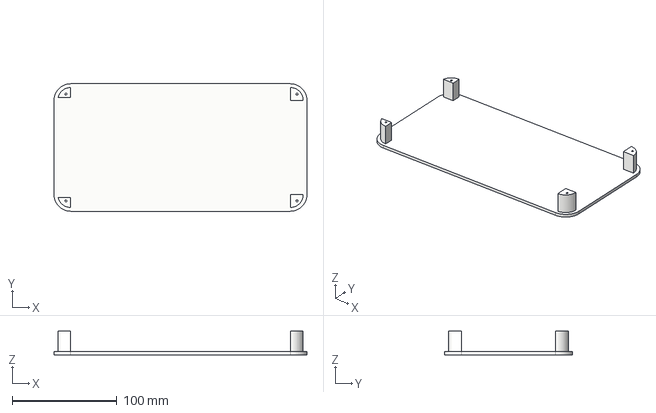
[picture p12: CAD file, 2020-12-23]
artdesign/fusion360/DoorForPrint.step
242.0 x 122.0 x 22.5 mm

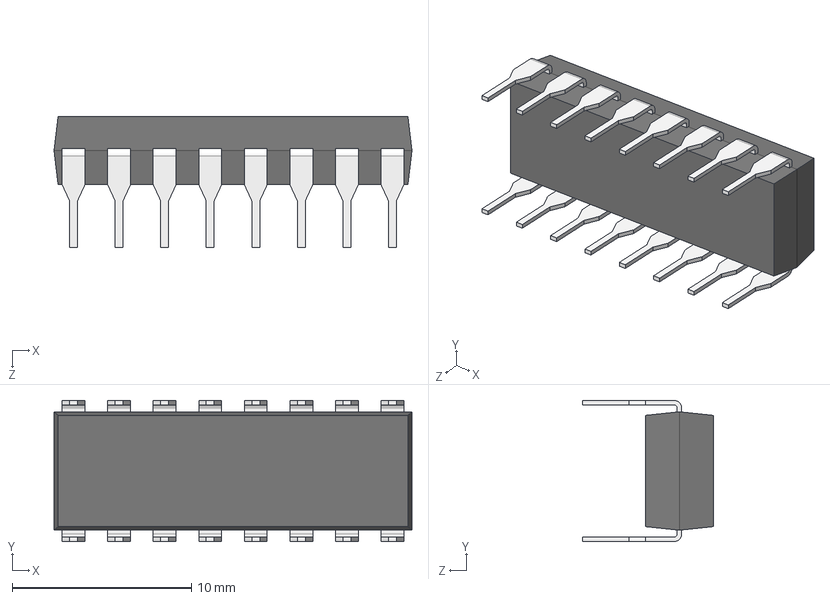
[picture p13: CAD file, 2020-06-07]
AltiumProject/componets/DIP16.STEP
20.0 x 7.87 x 7.30 mm

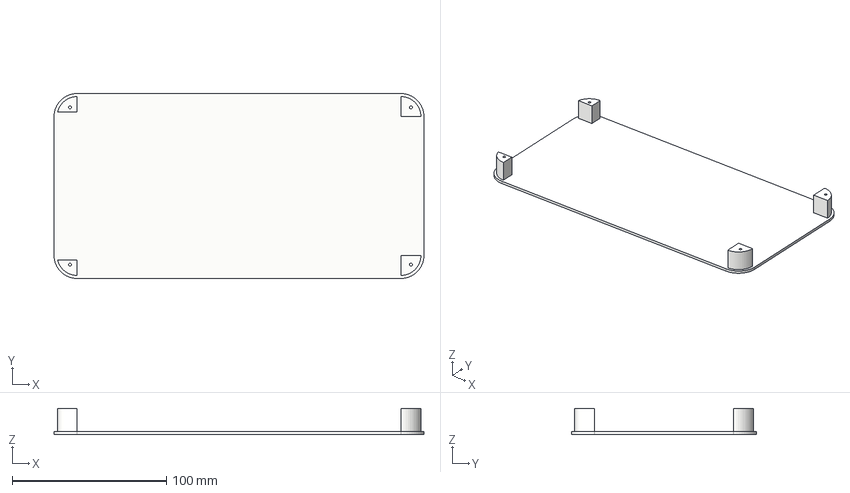
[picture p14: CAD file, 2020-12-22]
artdesign/fusion360/Door.step
240.0 x 120.0 x 17.0 mm

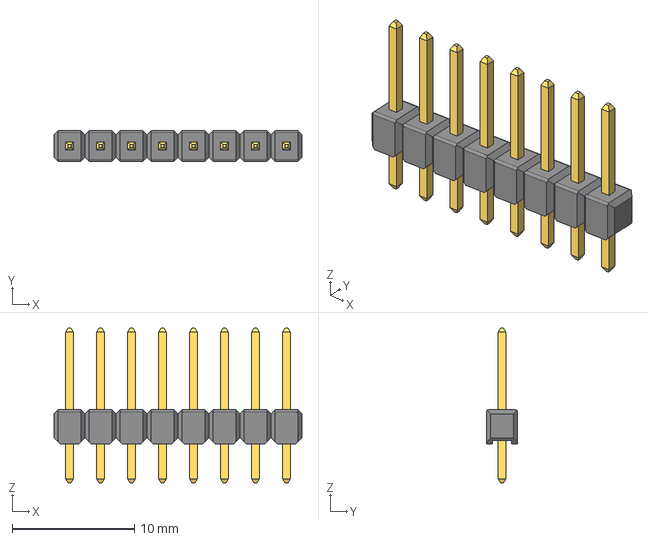
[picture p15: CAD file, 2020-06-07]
AltiumProject/componets/Pin Header 1x8 TH Pitch 2.54mm.stp
20.3 x 2.54 x 12.7 mm

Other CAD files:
artdesign/fusion360/Case.step
artdesign/fusion360/FlyBox2_ v30.f3d

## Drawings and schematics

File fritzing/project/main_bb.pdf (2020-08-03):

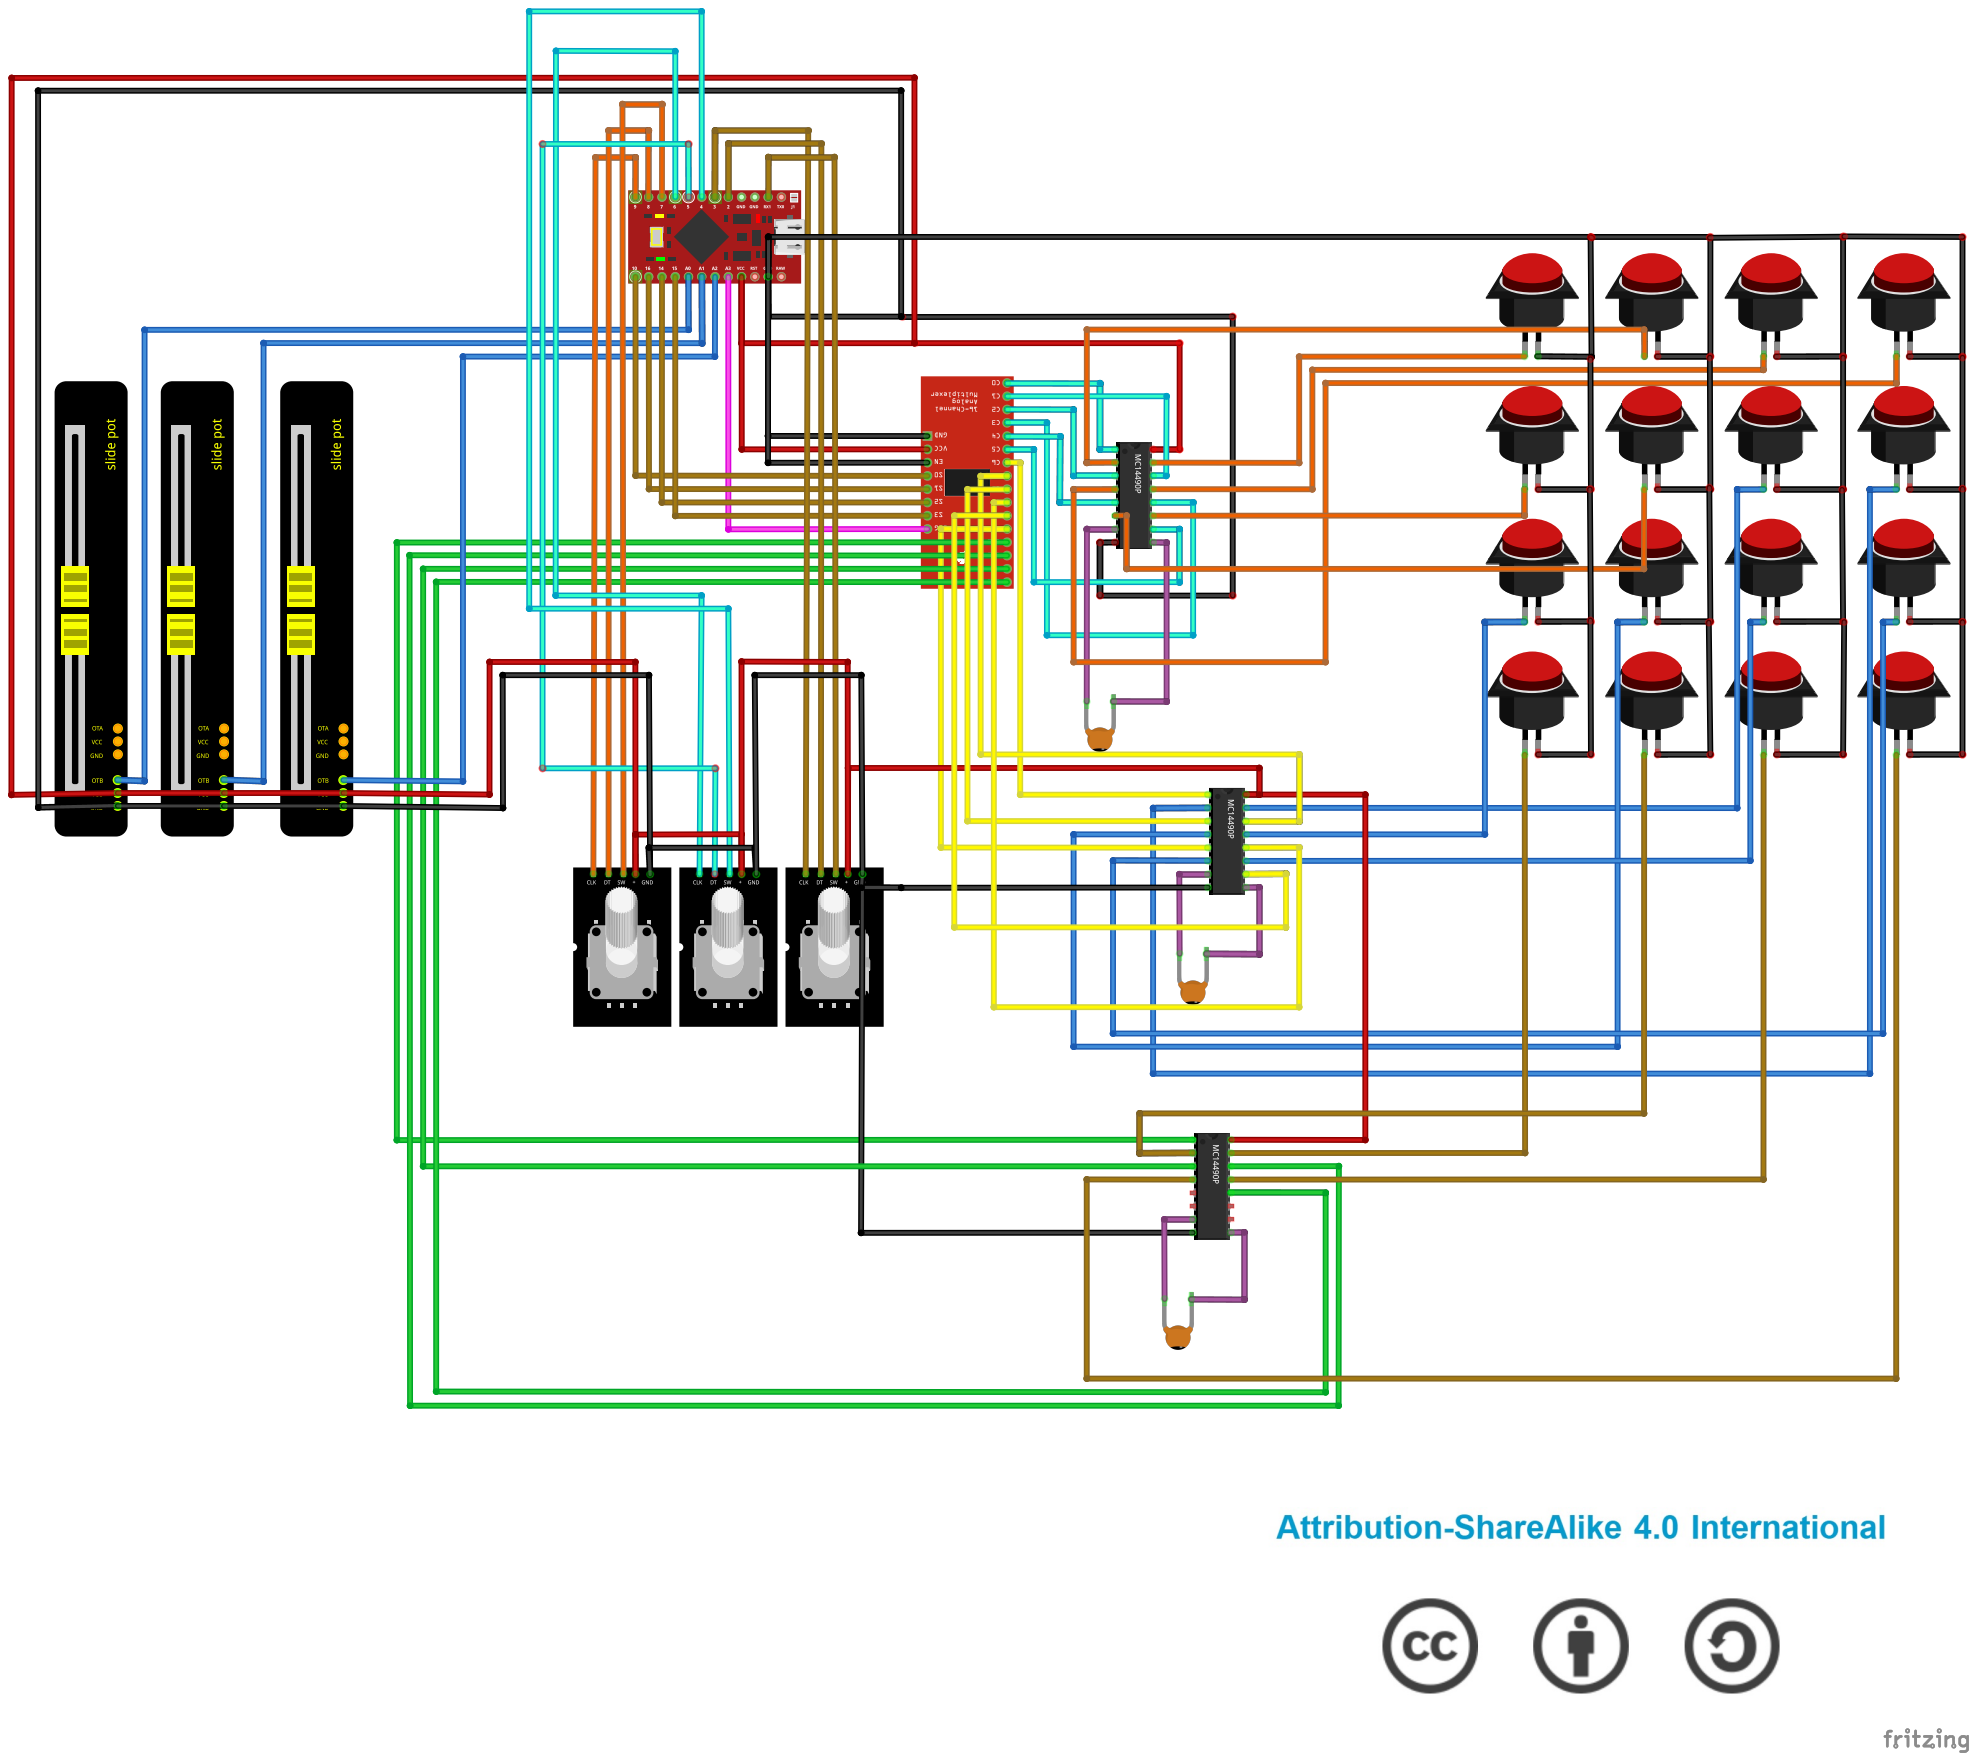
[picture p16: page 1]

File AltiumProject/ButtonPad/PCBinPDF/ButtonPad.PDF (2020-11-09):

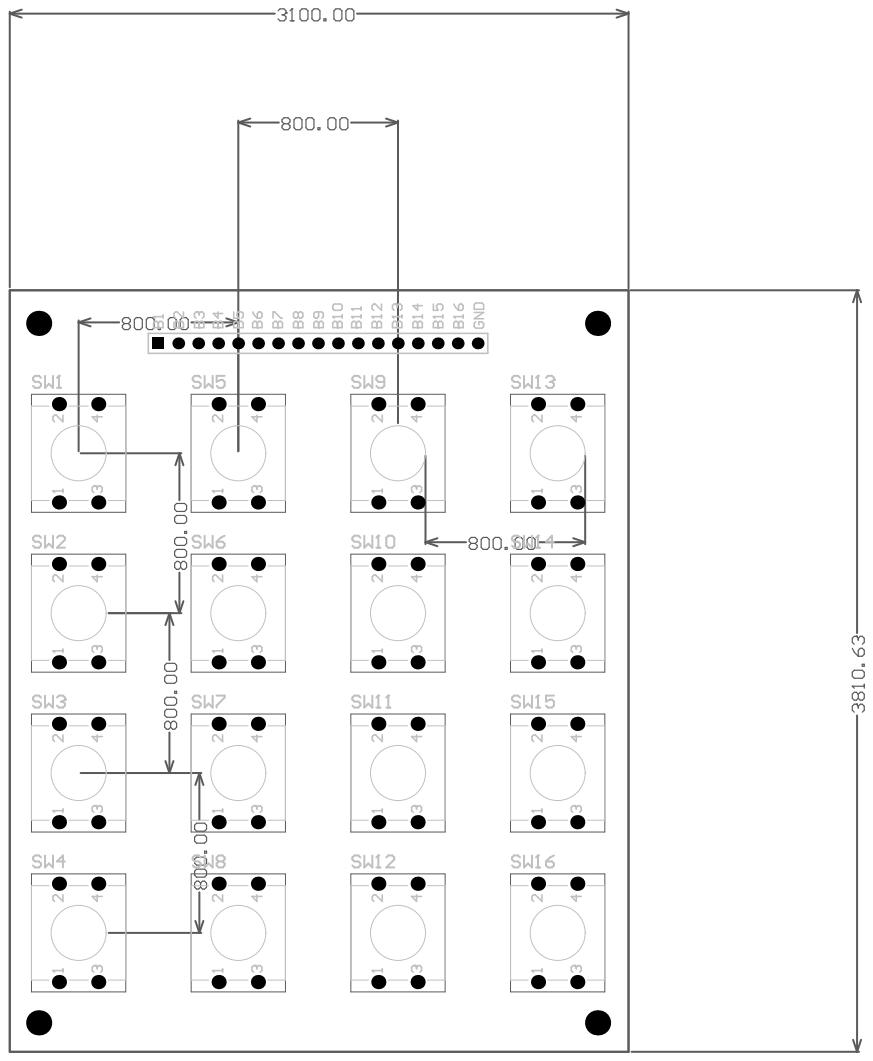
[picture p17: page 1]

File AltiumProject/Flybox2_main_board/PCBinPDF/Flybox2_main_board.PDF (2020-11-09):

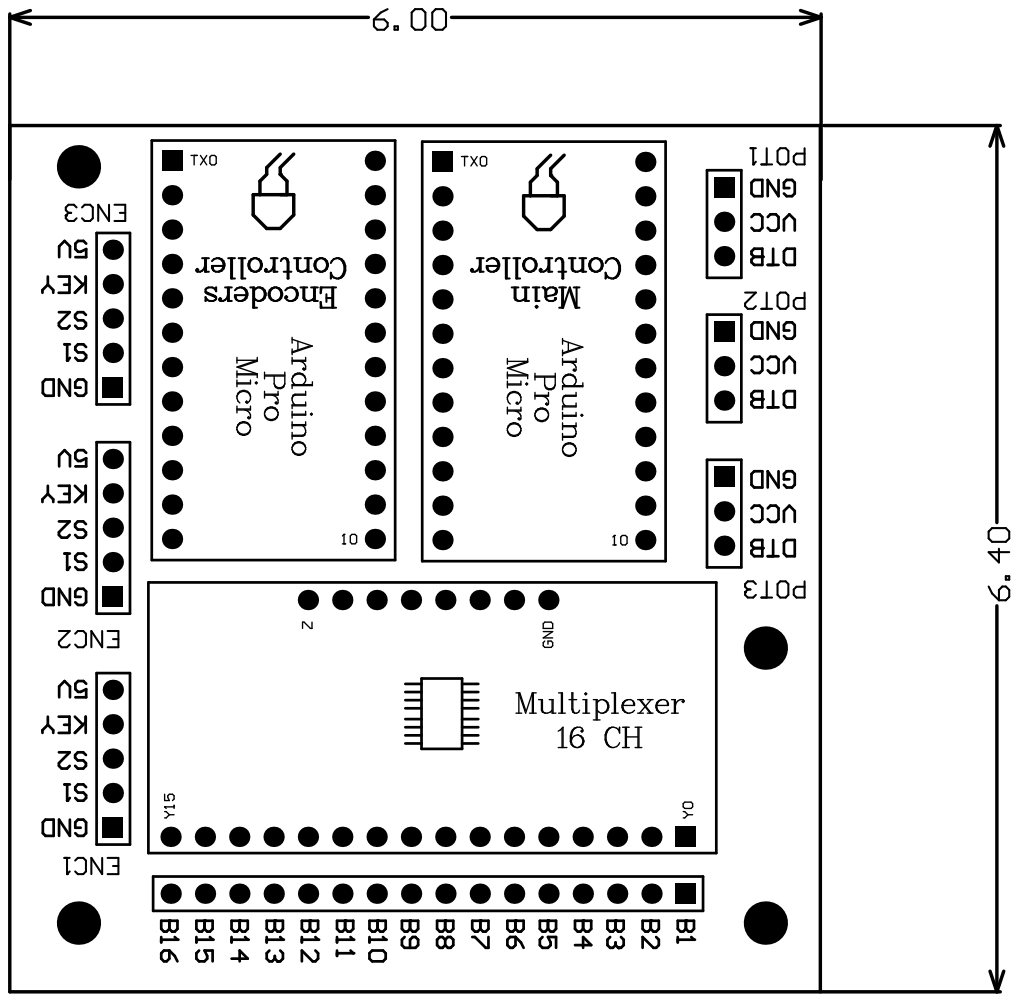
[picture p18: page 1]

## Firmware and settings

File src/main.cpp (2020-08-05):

/*
FlyBox2 is a flight simulator game pad for games like X-plane used together 
with a joystick 

Copyright (C) 2020  Andrea Mancini

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
You should have received a copy of the GNU General Public License
along with this program.  If not, see <https://www.gnu.org/licenses/>.
*/



#include <Arduino.h>
#include <ports.h>
#include <setports.h>
#include <setmicro.h>
#include <joyconf.h>
#include <emulator.h>
#include <logger.h>
#include <Timer.h>

// set test mode
bool t = false;

/* log activated
 * remember to stop log when using joytick
 * continuos print can disturb joystick functionality
 */
bool l = false;

Timer_ Timer_main;
Timer_ Enc_speed;

void setup() {

  setTest(t);  
  setLed();
  joy_conf();
  setEncoders();
  setMux();
  setPot();
}

void loop() {

  /* read input from axes not reversed
   * down = min value
   * up = max value
   */ 
  long x_pos = setX(SL_1, NO_REV);
  long y_pos = setY(SL_2, REV);
  long z_pos = setZ(SL_3, NO_REV);

  // order buttons from 1 to 16
  btArrayFiller();
  // read input form every mux port 
  muxLooper();
  // click one button or another depending by the encoder movement
  setEncoders_dir();

  if(t){
    /* reset all buttons to zero and click one
     * every timer time
     */
    if(Timer_main.expired(2000)){
      Timer_main.update();
      reset_bt_em();
      reset_enc_click_em();

      click_bt_em(random(16));
      click_enc_em(random(3,6));
      
    }     
    // move axis up and down; 
    loop_joy_em();

    //encoders
    if(Enc_speed.expired(500)){
      Enc_speed.update();
      click_enc_em();
      //Serial.println("pr1");
    } else {
      stop_enc();  
    }
    
    
    //Serial.println("pr2");
    
  }

  if(l){
    // print axes pos to monitor
    log_ax(x_pos, y_pos, z_pos);
  }
  
}

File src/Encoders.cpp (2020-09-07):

/*
FlyBox2 is a flight simulator game pad for games like X-plane used together 
with a joystick 

Copyright (C) 2020  Andrea Mancini

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
You should have received a copy of the GNU General Public License
along with this program.  If not, see <https://www.gnu.org/licenses/>.
*/

//my lib
#include <Encoders.h>
//#include<Encoder.h>



Encoders_::Encoders_(int clk, int dt, int sw){

  _MyEnc = new Encoder(clk, dt);
  
  _clk = clk;
  _dt = dt;
  _sw = sw;

  _last_enc_pos = -99999;

  _dir = 0;
 

  _sw_last_state = HIGH;

  _sw_read = HIGH;

  _res = HIGH;
  
}



int Encoders_::direction(long out_t){
  
  long newpos = _MyEnc->read();

  //Serial.println(newpos);

  if(_Timer2.expired(out_t)){
    
    if(newpos ==_last_enc_pos) _dir = 0;
    else if(newpos < _last_enc_pos) _dir = -1;
    else _dir = 1; 
    _Timer2.update();
  }

  

  _last_enc_pos = newpos;

  

    
  //Serial.println(_dir);

  return _dir;
}

int Encoders_::ext_direction(long out_t){
  
  int left = digitalRead(_clk);
  //Serial.println(left);
  int right = digitalRead(_dt);
  //Serial.println(right);
    
  if(left) _dir = -1;
  else if(right) _dir = 1;
  else _dir = 0;
  return _dir;
}

int Encoders_::click(long deb_time){

    
  // read the state of the switch into a local variable:
  // normal open state is HIGH
  _sw_read = digitalRead(_sw);

  /*if(_sw_read) Serial.println("HIGH");
  else Serial.println("LOW");*/
  
  /*save the state before timer check to not stuck on a
  specific state*/
  _sw_last_state = _sw_read;

  //Serial.println(_sw_last_state);

  if(_Timer1.expired(deb_time)){
    _Timer1.update();
    if (!_sw_read){
      return 0;
    } else {
      return 1;
    } 
  }

  
  return _sw_last_state;
}

int Encoders_::lastState(){
  return _res;
}

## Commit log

2020-06-02 PCB and Schematics
    [MC14490P_module_PCB.SchDoc, PCB1.PcbDoc, Schlib1.SchLib]
2020-06-07 altium mc14490P schematics
    [10pF Ceramic Disc 2.SLDPRT, DIP16.STEP, MC14490P_module_PCB.SchDoc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]
2020-06-08 PCB complete ready for printing
    [PCB1.PcbDoc]
2020-06-29 pcb updated
    [PCB1.GBL, PCB1.GBO, PCB1.GBP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]
2020-07-02 header 7 pin number fixed
    [MC14490P_module_PCB.SchDoc, PCB1.PcbDoc, Schlib1.SchLib]
2020-07-03 PCB finish ready to print and README update
    [MC14490P_module_PCB.SchDoc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]
2020-08-03 for print to assemble
2020-08-05 try to fix click encoders
    [Encoder.cpp, joyconf.cpp, main.cpp]
2020-08-11 fix encoder click debounce
    [Encoder.cpp]
2020-08-11 try fixing encoder click
    [Encoder.cpp, joyconf.cpp]
2020-08-13 encoder click debounce fixed
    [Encoder.cpp, joyconf.cpp, timer.cpp]
2020-08-14 encoder improved
2020-08-18 encoder need interrupt pins
2020-08-18 Arduino pinout added
2020-08-18 new pinout for interrupts
    [main.fzz]
2020-08-18 building button object
2020-08-19 add software button debounce
2020-08-24 fix port for interrupts
    [joyconf.cpp, ports.h]
2020-08-26 zero delay for interrupts
2020-09-06 - fix pinout encoder - encoder input signal not working
    [Encoders.cpp, joyconf.cpp, ports.h]
2020-09-07 -encoder improvements
2020-09-07 serial print off for better performance
2020-09-09 - installation instructions - assembling scheme with encoder controller
    [main_with_module.fzz]
2020-09-14 project rewiring for PCB production
    [main_with_module.fzz]
2020-09-19 - still design PCB - better fritzing schematics
    [10pF Ceramic Disc 2.SLDPRT, DIP16.STEP, FlyBox2.PcbLib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]
2020-09-19 - fix schematics
    [FlyBox2.PcbLib, FlyBox2.PrjPcb, Flybox2_main_board.PcbDoc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]
2020-09-30 - designed components - started FlyBox2 board schematic
    [10pF Ceramic Disc 2.SLDPRT, DIP16.STEP, FlyBox2.PcbLib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]
2020-10-03 writing ports
    [Flybox2_main_board.SchDoc]
2020-10-23 schematics wiring complete
    [Flybox2_main_board.SchDoc]
2020-10-29 Altium rebuild and project refactoring
    [10pF Ceramic Disc 2.SLDPRT, DIP16.STEP, FlyBox2.PcbLib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]
2020-10-29 moving and put in order gerber files
    [PCB1.DRL, PCB1.GBL, PCB1.GBO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]
2020-10-29 - fix schematics - update fritzing pin names
    [Flybox2_main_board.SchDoc, MC14490P_module_PCB.SchDoc, main_with_module.fzz]
2020-11-01 routing pcb
    [Flybox2_main_board.PcbDoc, Flybox2_main_board.SchDoc, MC14490P_module_PCB.PcbDoc]
2020-11-05 - new folder and file moved - PCB main board ready to print - designing buttonpad PCB
    [ButtonPad.PcbDoc, ButtonPad.PrjPcb, ButtonPad.SchDoc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]
2020-11-09 - finish design button pad - designing breakouts
    [ButtonPad.PcbDoc, Encoder_Breakout_Module.PrjPcb, PcbLib1.PcbLib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]
2020-11-10 - all the boards ready for print
    [ButtonPad.PcbDoc, ButtonPad.PrjPcb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]
2020-11-10 fritzing updated
    [main_with_module.fzz]
2020-11-11 altium backup files
    [ButtonPad.PrjPcb, Encoder_Breakout_Module.PrjPcb]
2020-12-02 - pinout changed for board - notes on fritzing
    [main_with_module.fzz]
2020-12-02 - switched enc2 with 3
2020-12-02 - change fritzing
    [main_with_module.fzz]
2020-12-22 box for 3d printing
    [Case.step, Door.step, FlyBox2 case v29.f3d]
2020-12-23 model 3d fixed for 3d printing
    [CaseForPrint.step, DoorForPrint.step, FlyBox2 case v29.f3d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]

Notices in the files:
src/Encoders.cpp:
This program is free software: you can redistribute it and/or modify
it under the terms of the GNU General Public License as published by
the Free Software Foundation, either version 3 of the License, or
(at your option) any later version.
